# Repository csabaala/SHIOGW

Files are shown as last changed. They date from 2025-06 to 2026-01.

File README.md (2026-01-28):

# [SHIOGW](/Hardware/SHIOGW)

DIN rail mount extension board for [Olimex ESP32-GATEWAY](https://www.olimex.com/Products/IoT/ESP32/ESP32-GATEWAY/open-source-hardware).

More [Pictures](/Pictures#assembled-boards) and [Video](https://youtu.be/ds2y22MUNzQ) of the assembled board and extensions.

Example [ESPHome configs](/ESPHome)

## Features

* 12V to 5V step-down converter
* 2 open collector output (50 mA load per channel)
* 2 opto isolated input
* LEDs for output and input status
* 2 sensor input (ds18b20, dht)
* RS-485 interface
* 4 pin JST connector for I2C extensions
* 14 pin IDC connector for direct GPIO access

View [3D model](https://3dviewer.net/#model=https://github.com/csabaala/SHIOGW/blob/main/Hardware/SHIOGW/SHIOGW.wrl)

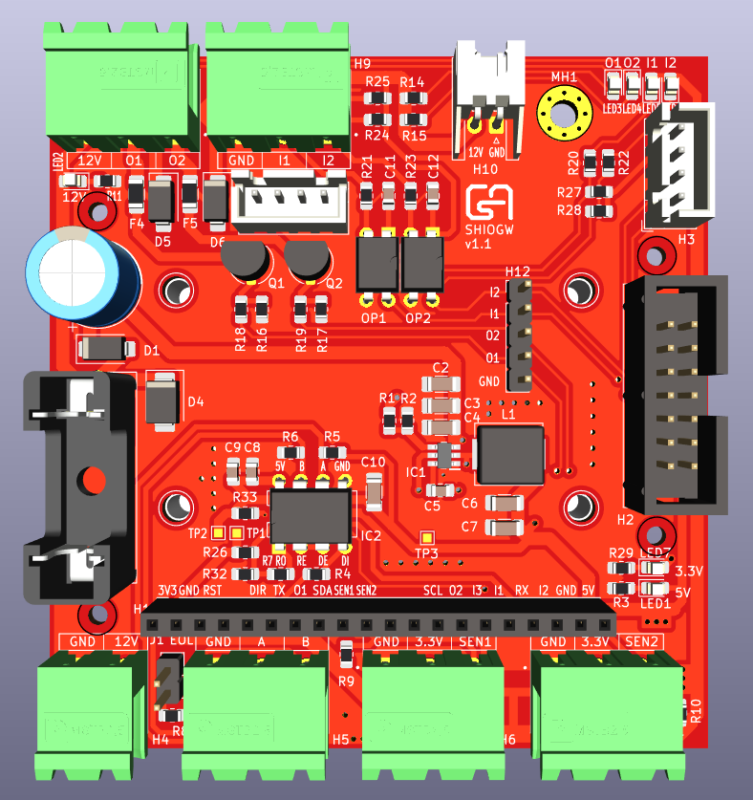
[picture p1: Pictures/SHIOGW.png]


## Extensions

### [GWHMI](/Hardware/GWHMI)

Control interface for SHIOGW.

* PCB for 128x64 OLED display and control buttons. Fits the 0.96 and 1.3 inch OLED versions.
* Mountable top of the SHIOGW board.
* Connects to SHIOGW's 12 pin IDC connector with a small ribbon cable.
* BTN1 (up) and BTN3 (down) shared with I1 and I2 on SHIOGW main board.

View [3D model](https://3dviewer.net/#model=https://github.com/csabaala/SHIOGW/blob/main/Hardware/GWHMI/GWHMI.wrl)

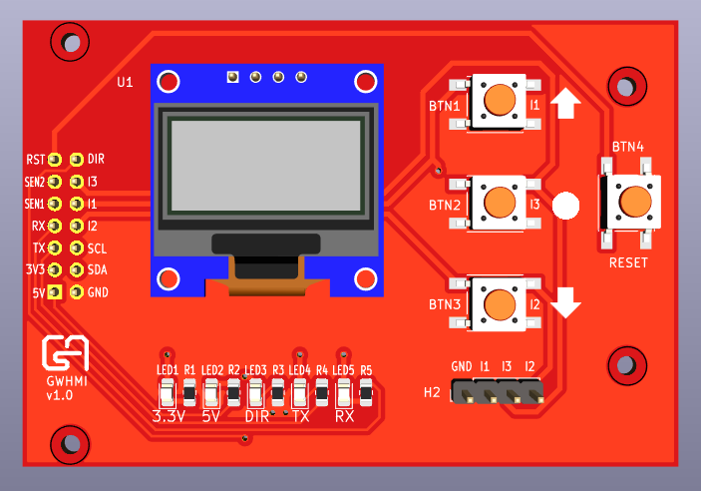
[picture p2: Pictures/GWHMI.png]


### [SHIO88E](/Hardware/SHIO88E)

I2C IO extension.

* MCP23017 based
* 8 open collector output (50 mA load per channel)
* 8 opto isolated input
* LEDs for output and input status
* One more I2C connector to connect other device

View [3D model](https://3dviewer.net/#https://github.com/csabaala/SHIOGW/blob/main/Hardware/SHIO88E/SHIO88E.wrl)

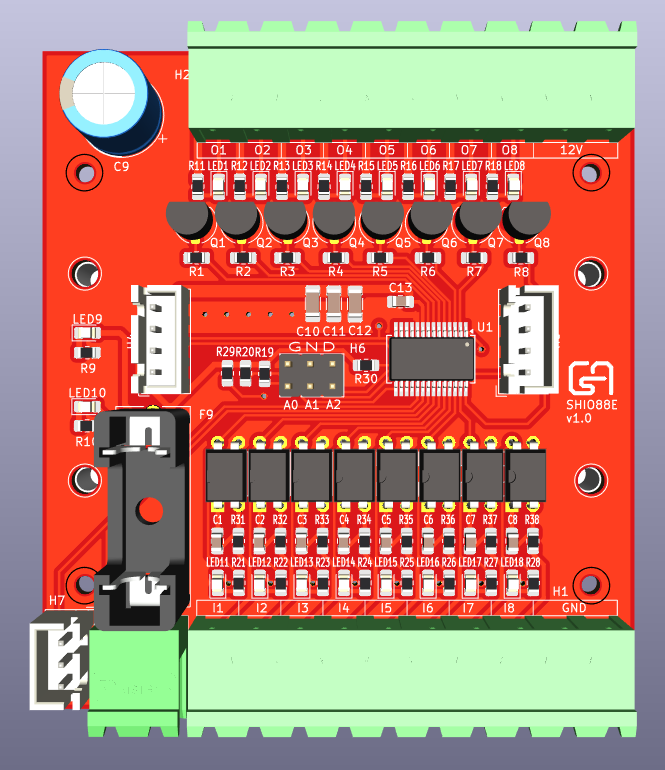
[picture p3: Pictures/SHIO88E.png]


### [LRMNT](/Hardware/LRMNT)

Adapter PCB to mount [Heltec LoRa 32 V3](https://heltec.org/project/wifi-lora-32-v3/) module to SHIOGW board.

* 2 extra open collector output (50 mA load per channel)
* 4 extra opto isolated input

View [3D model](https://3dviewer.net/#https://github.com/csabaala/SHIOGW/blob/main/Hardware/LRMNT/LRMNT.wrl)

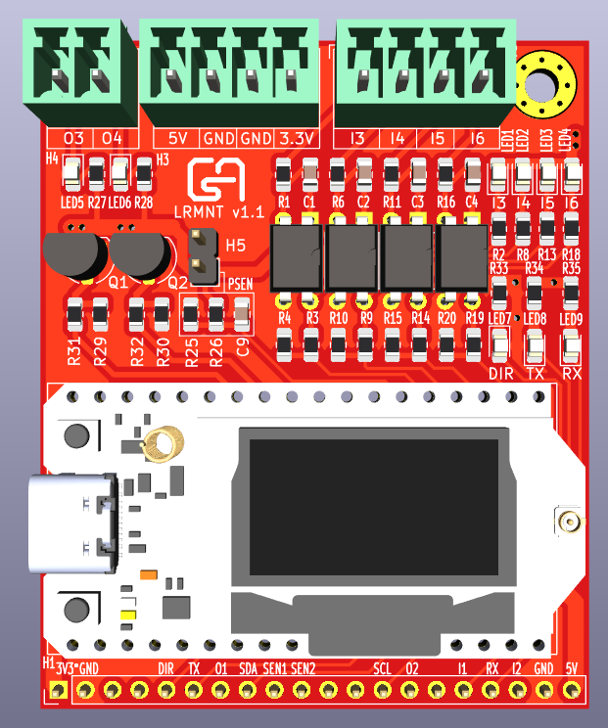
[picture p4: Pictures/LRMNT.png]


### [SHIOADS](/Hardware/SHIOADS)

Din rail mount breakout board for ADS1115 module.

* On board voltage divider resistors (R1 - R8)
* Solder jumpers to set I2C address (JP1 - JP4)

View [3D model](https://3dviewer.net/#https://github.com/csabaala/SHIOGW/blob/main/Hardware/SHIOADS/SHIOADS.wrl)

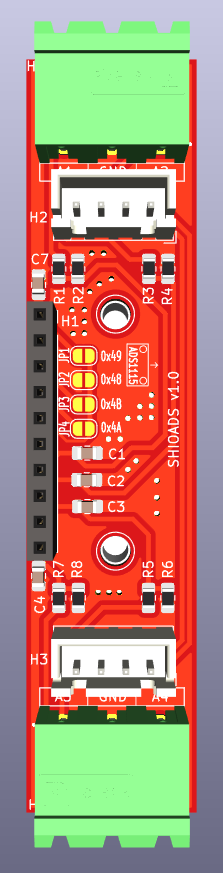
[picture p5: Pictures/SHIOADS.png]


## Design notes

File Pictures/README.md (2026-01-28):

## Assembled boards

The SMD components sitting on the front side of the SHIOGW and SHIOE boards manufactured by JLCPCB SMT assembly.

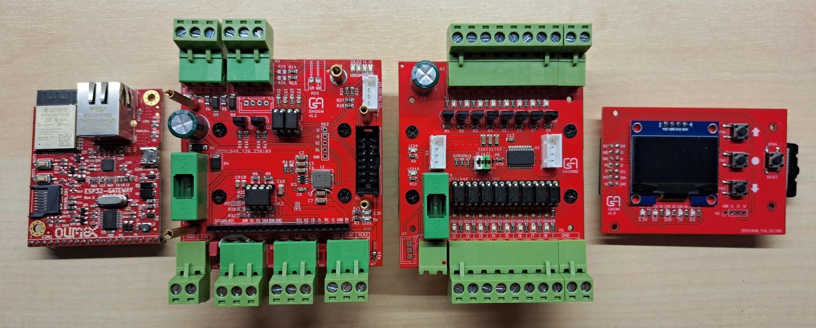
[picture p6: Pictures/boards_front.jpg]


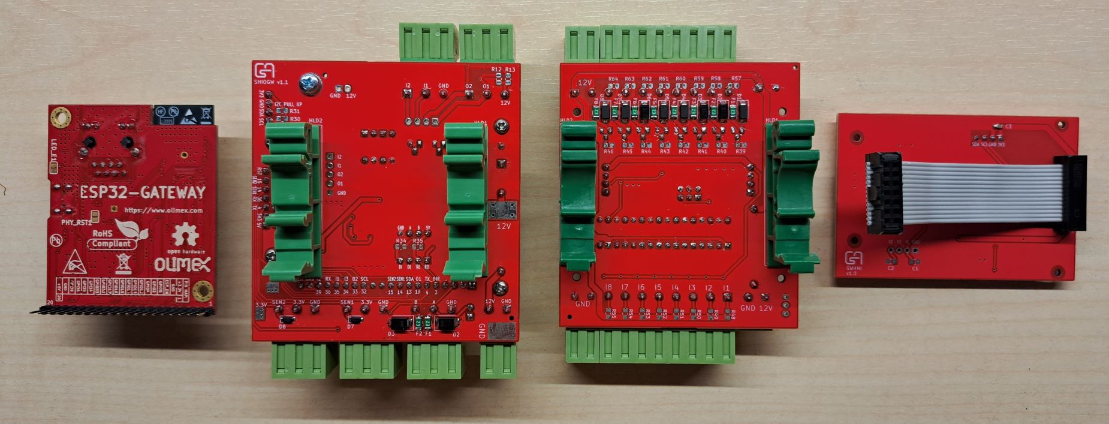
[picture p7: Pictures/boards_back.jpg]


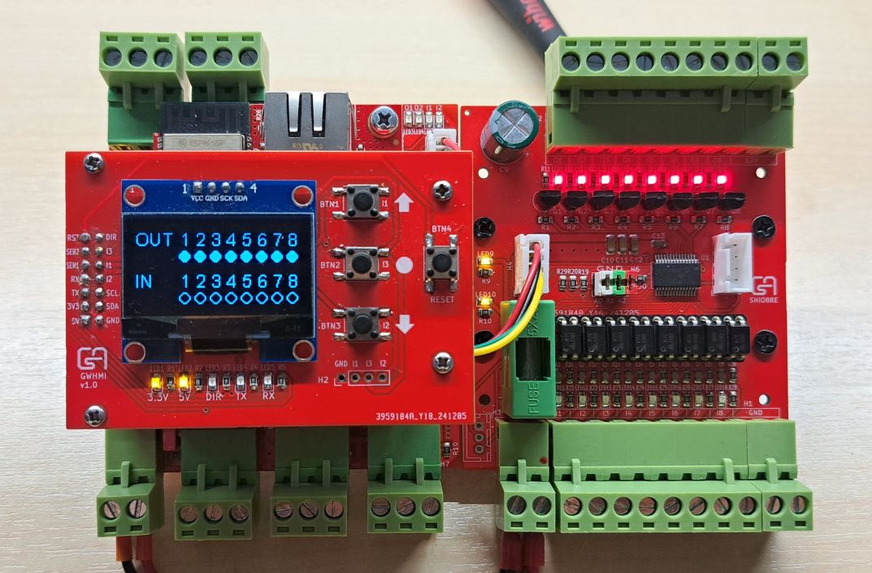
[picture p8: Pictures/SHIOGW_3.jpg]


Fits into home distribution boxes:

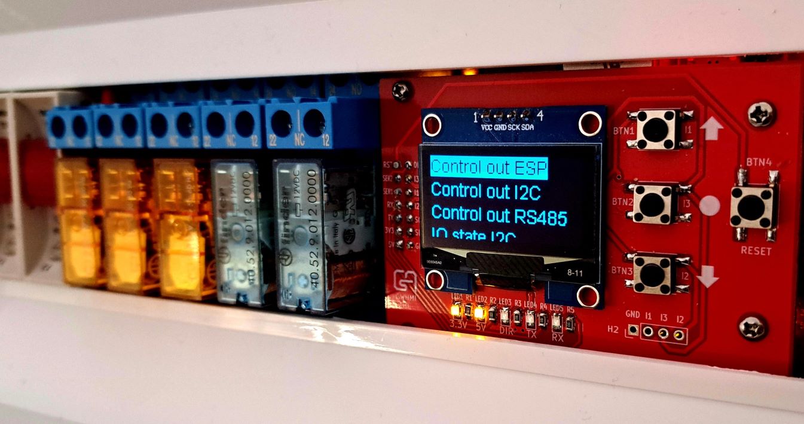
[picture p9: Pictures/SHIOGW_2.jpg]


## SHIOGW and Olimex Gateway

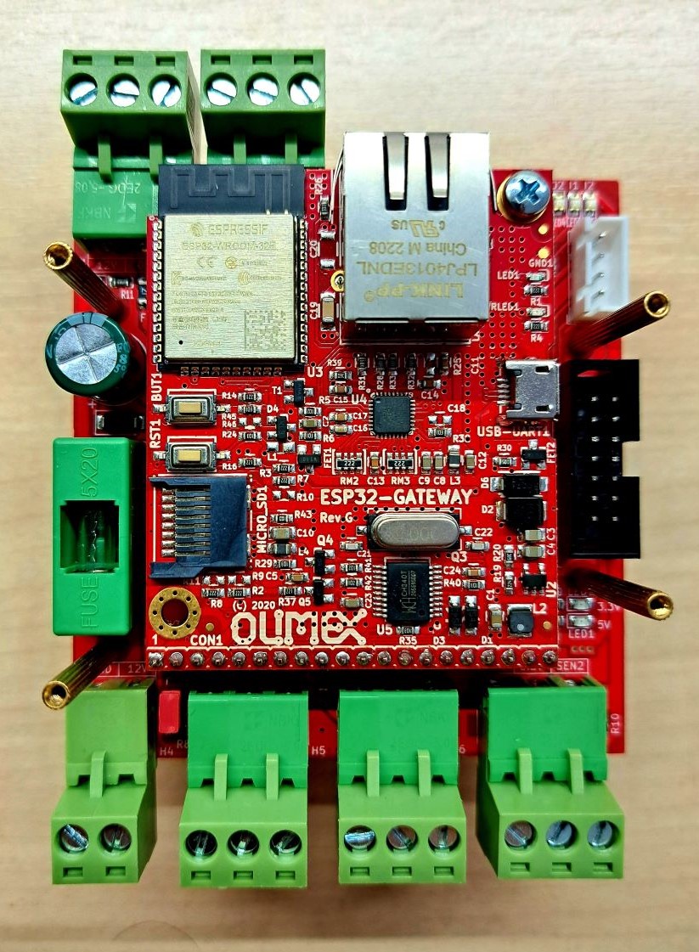
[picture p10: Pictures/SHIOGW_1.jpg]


## SHIO88E

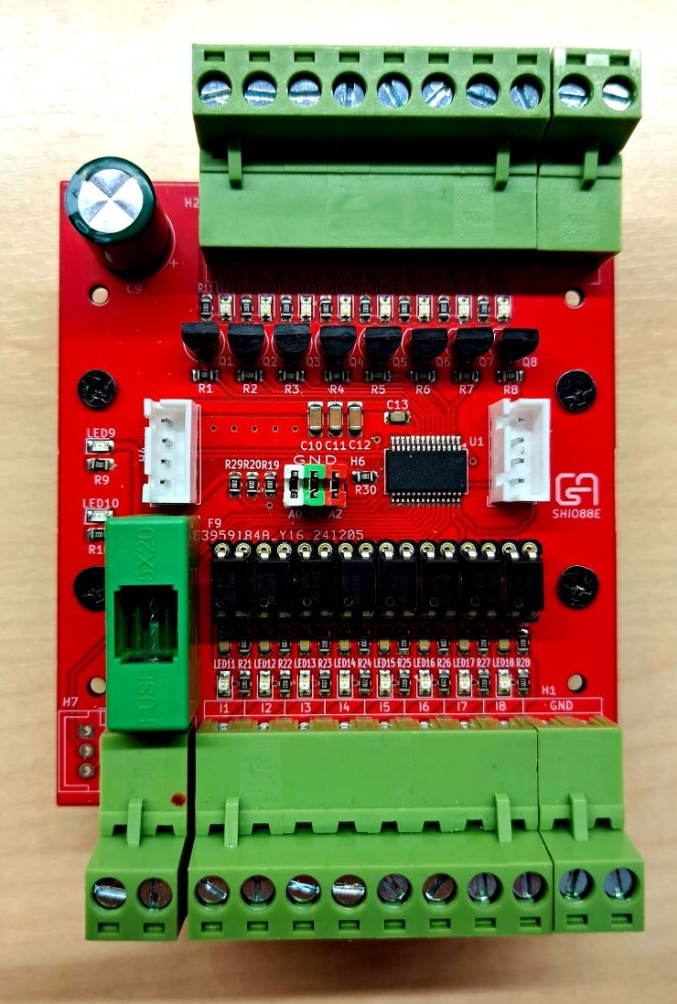
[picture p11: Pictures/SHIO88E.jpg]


## 3D images

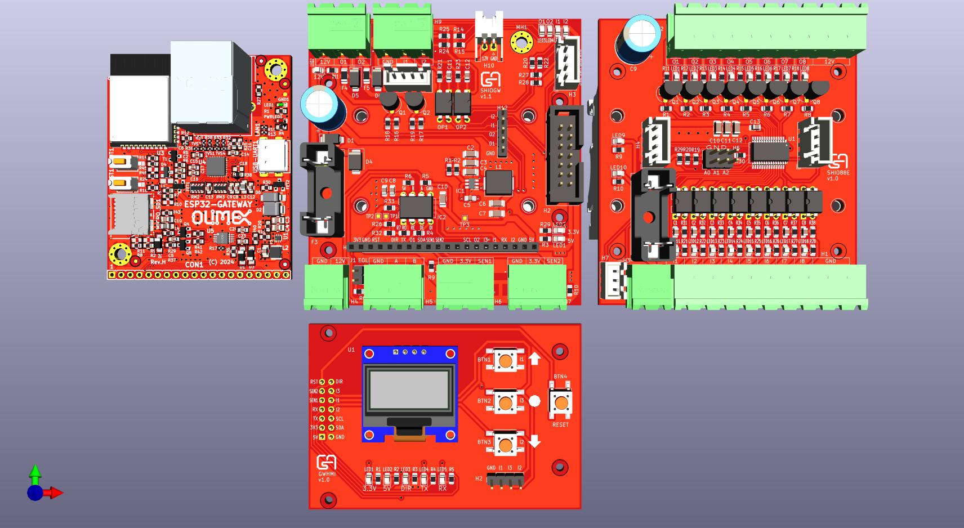
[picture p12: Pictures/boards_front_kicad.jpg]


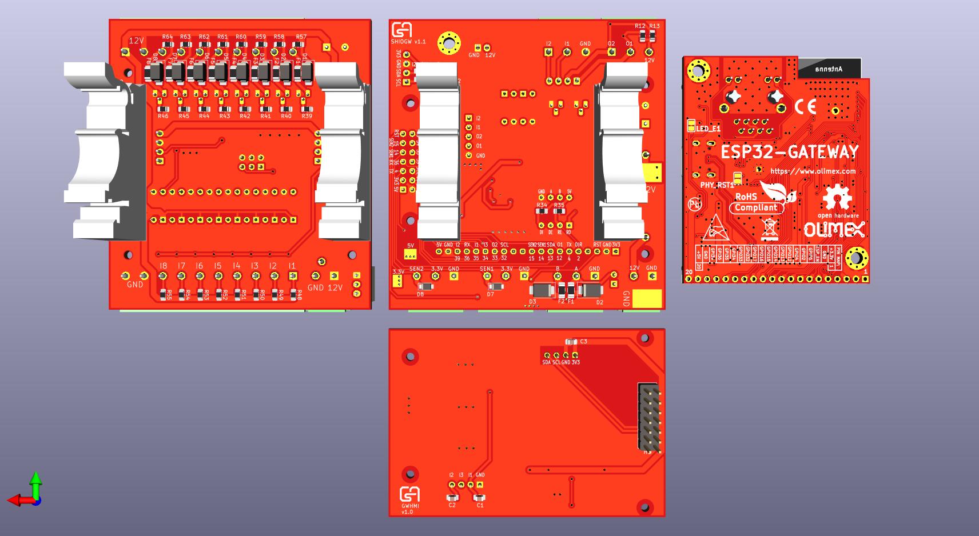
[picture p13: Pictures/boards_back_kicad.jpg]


## LRMNT & SHIOADS

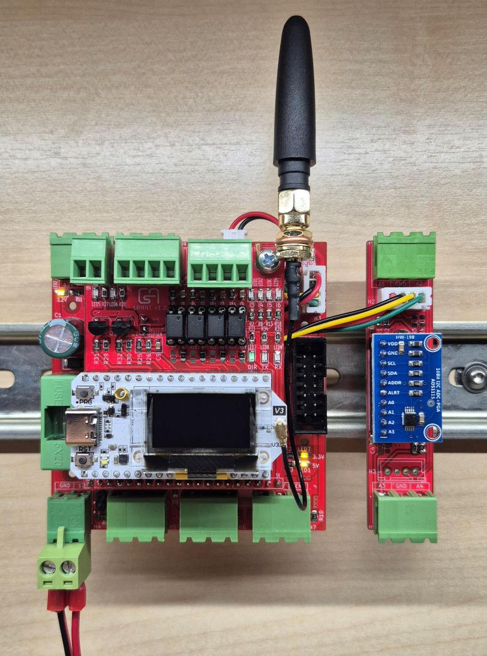
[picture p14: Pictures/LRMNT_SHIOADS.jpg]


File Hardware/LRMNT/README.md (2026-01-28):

# Assembly information
## 12V power source
To activate the additional digital input and output channels, connect the power source to the H5 header.
You can connect to the SHIOGW H10 connector using a JST cable.

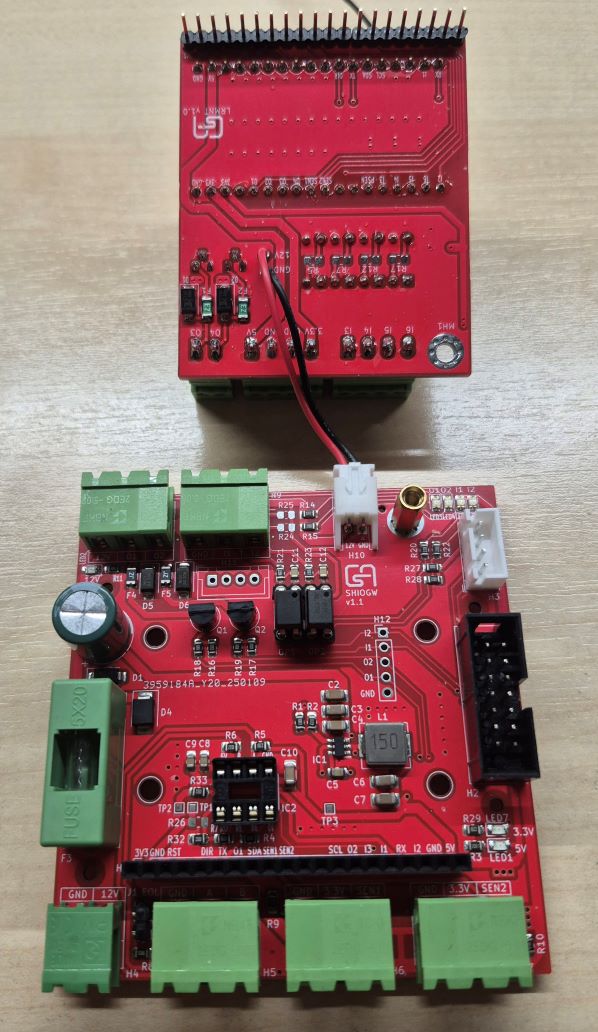
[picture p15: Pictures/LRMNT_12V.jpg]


## Using input channel as ADC
You can soldering the input channels (I3 - I5) to use as ADC (Analog to Digital Converter) input.
To enable ADC reading solder the following parts (for example for I3 channel):

* R1: 0 ohm
* R5: 0 ohm (to bypass OP1)
* R3: Voltage divider high resistor 
* R4: Voltage divider low resistor 
* C5: 100 nF capacitor

Do not solder:

* OP1
* C1

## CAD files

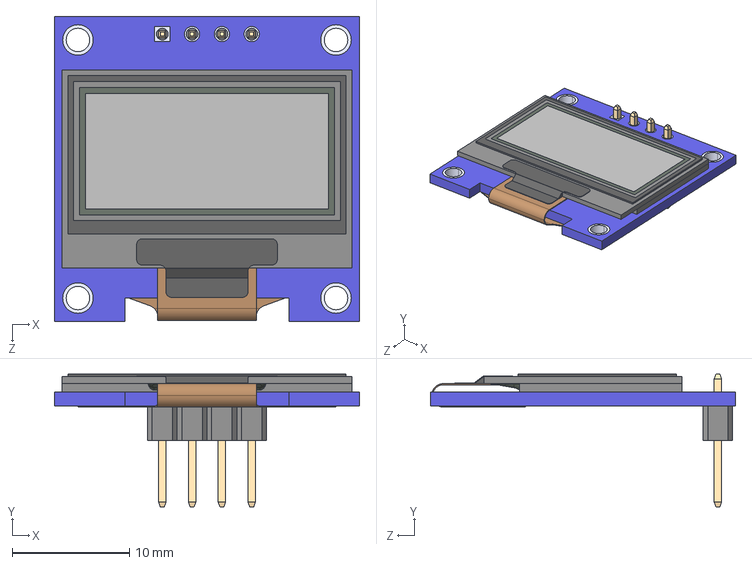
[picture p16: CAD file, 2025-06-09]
Hardware/GWHMI/extras/DM-OLED096-636.step
26.0 x 11.3 x 26.0 mm
DM-OLED096-636_Module
DM-OLED096-636_Panel

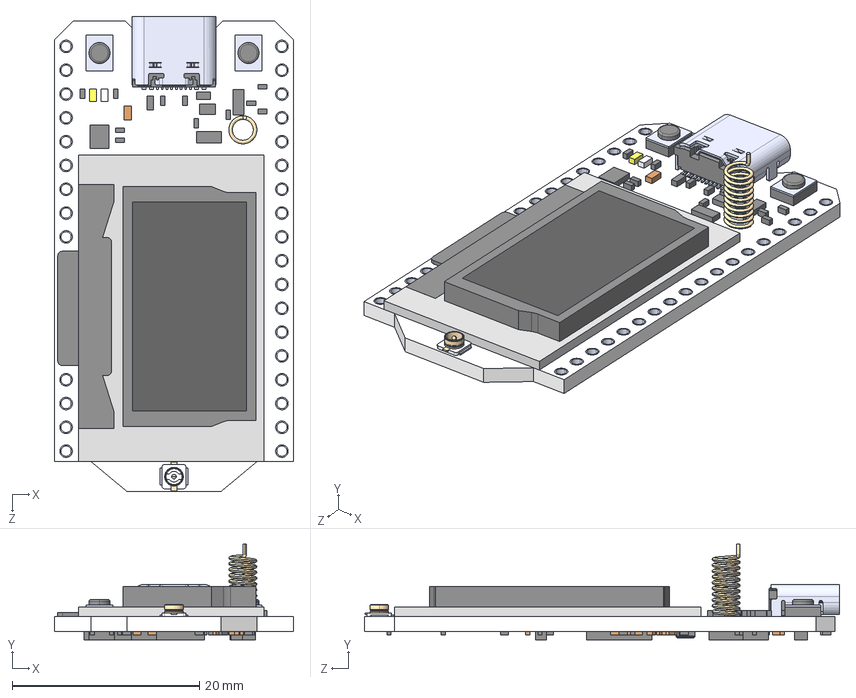
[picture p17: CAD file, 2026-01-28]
Hardware/LRMNT/extras/WIFI_KIT_32__V3_.step
25.5 x 10.2 x 50.7 mm

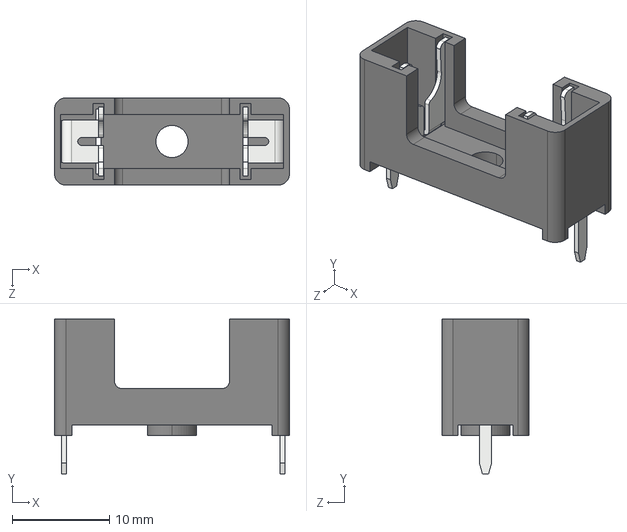
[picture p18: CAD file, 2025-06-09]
Hardware/SHIO88E/extras/fuse/fuse_3d.STEP
24.2 x 16.0 x 8.99 mm

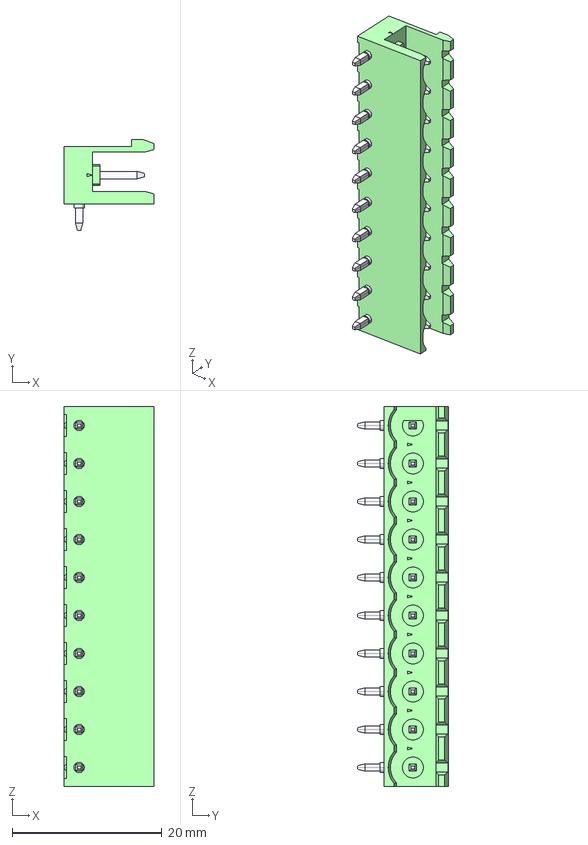
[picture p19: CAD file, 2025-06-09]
Hardware/SHIO88E/extras/MSTB 2,5-10-G-5,08.stp
12.0 x 12.1 x 50.8 mm

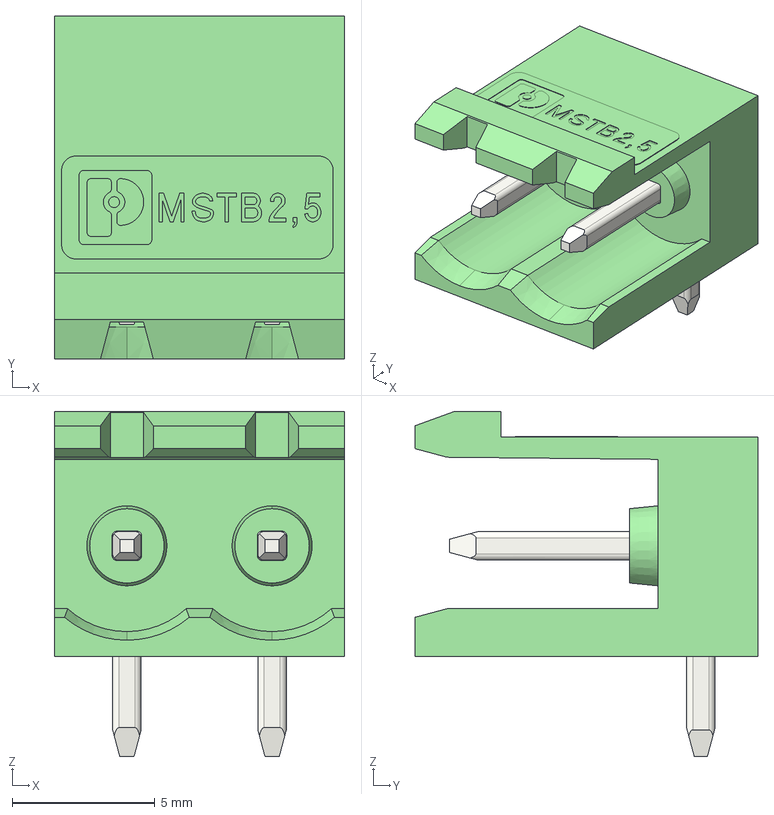
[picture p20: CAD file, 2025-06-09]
Hardware/LRMNT/extras/MSTB 2,5-2-G-5,08.step
10.2 x 12.0 x 12.1 mm

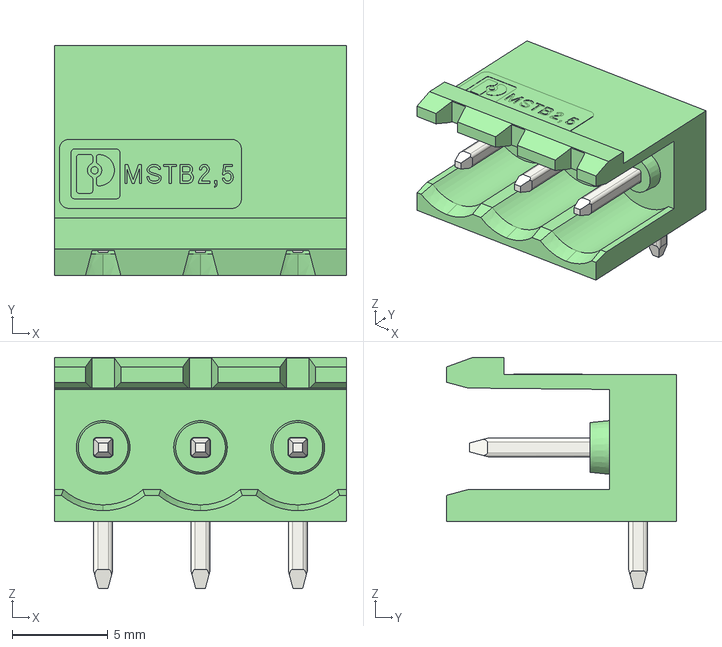
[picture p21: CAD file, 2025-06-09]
Hardware/LRMNT/extras/MSTB 2,5 3-G-5,08/1759020.step
15.2 x 12.0 x 12.1 mm

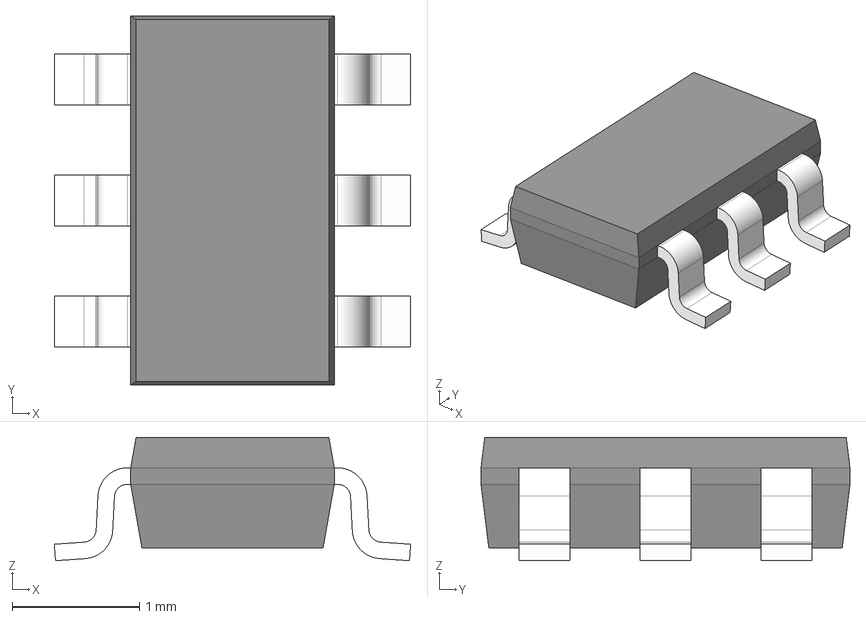
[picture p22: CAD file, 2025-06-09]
Hardware/SHIOGW/extras/LMR51420/LMR51420XDDCR.stp
2.80 x 2.90 x 0.97 mm
BODY-SOT
LEAD-SOT x 6

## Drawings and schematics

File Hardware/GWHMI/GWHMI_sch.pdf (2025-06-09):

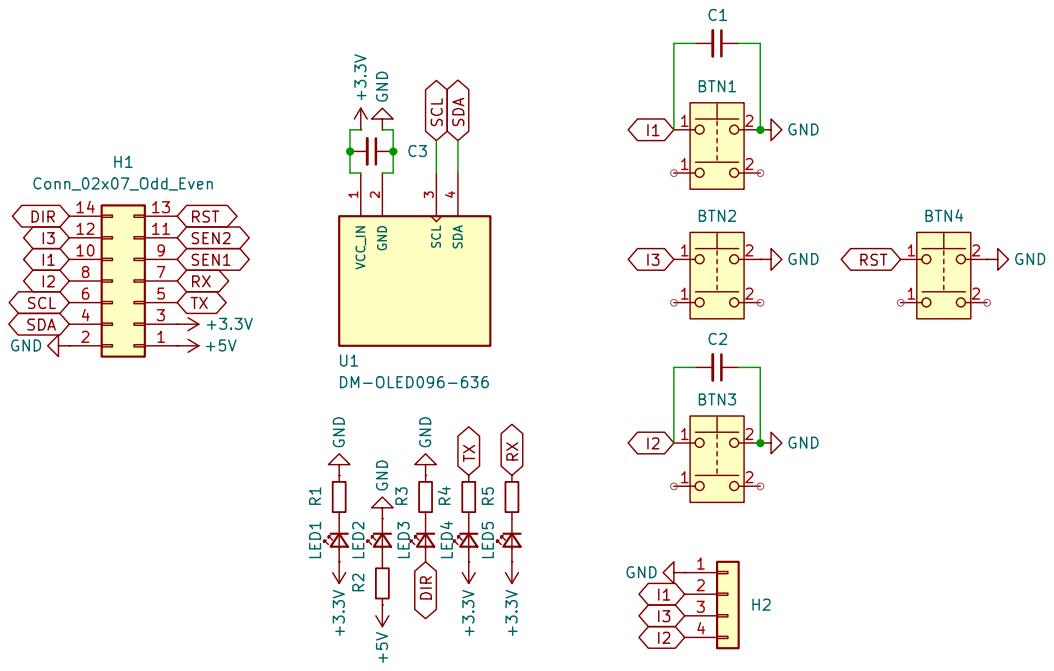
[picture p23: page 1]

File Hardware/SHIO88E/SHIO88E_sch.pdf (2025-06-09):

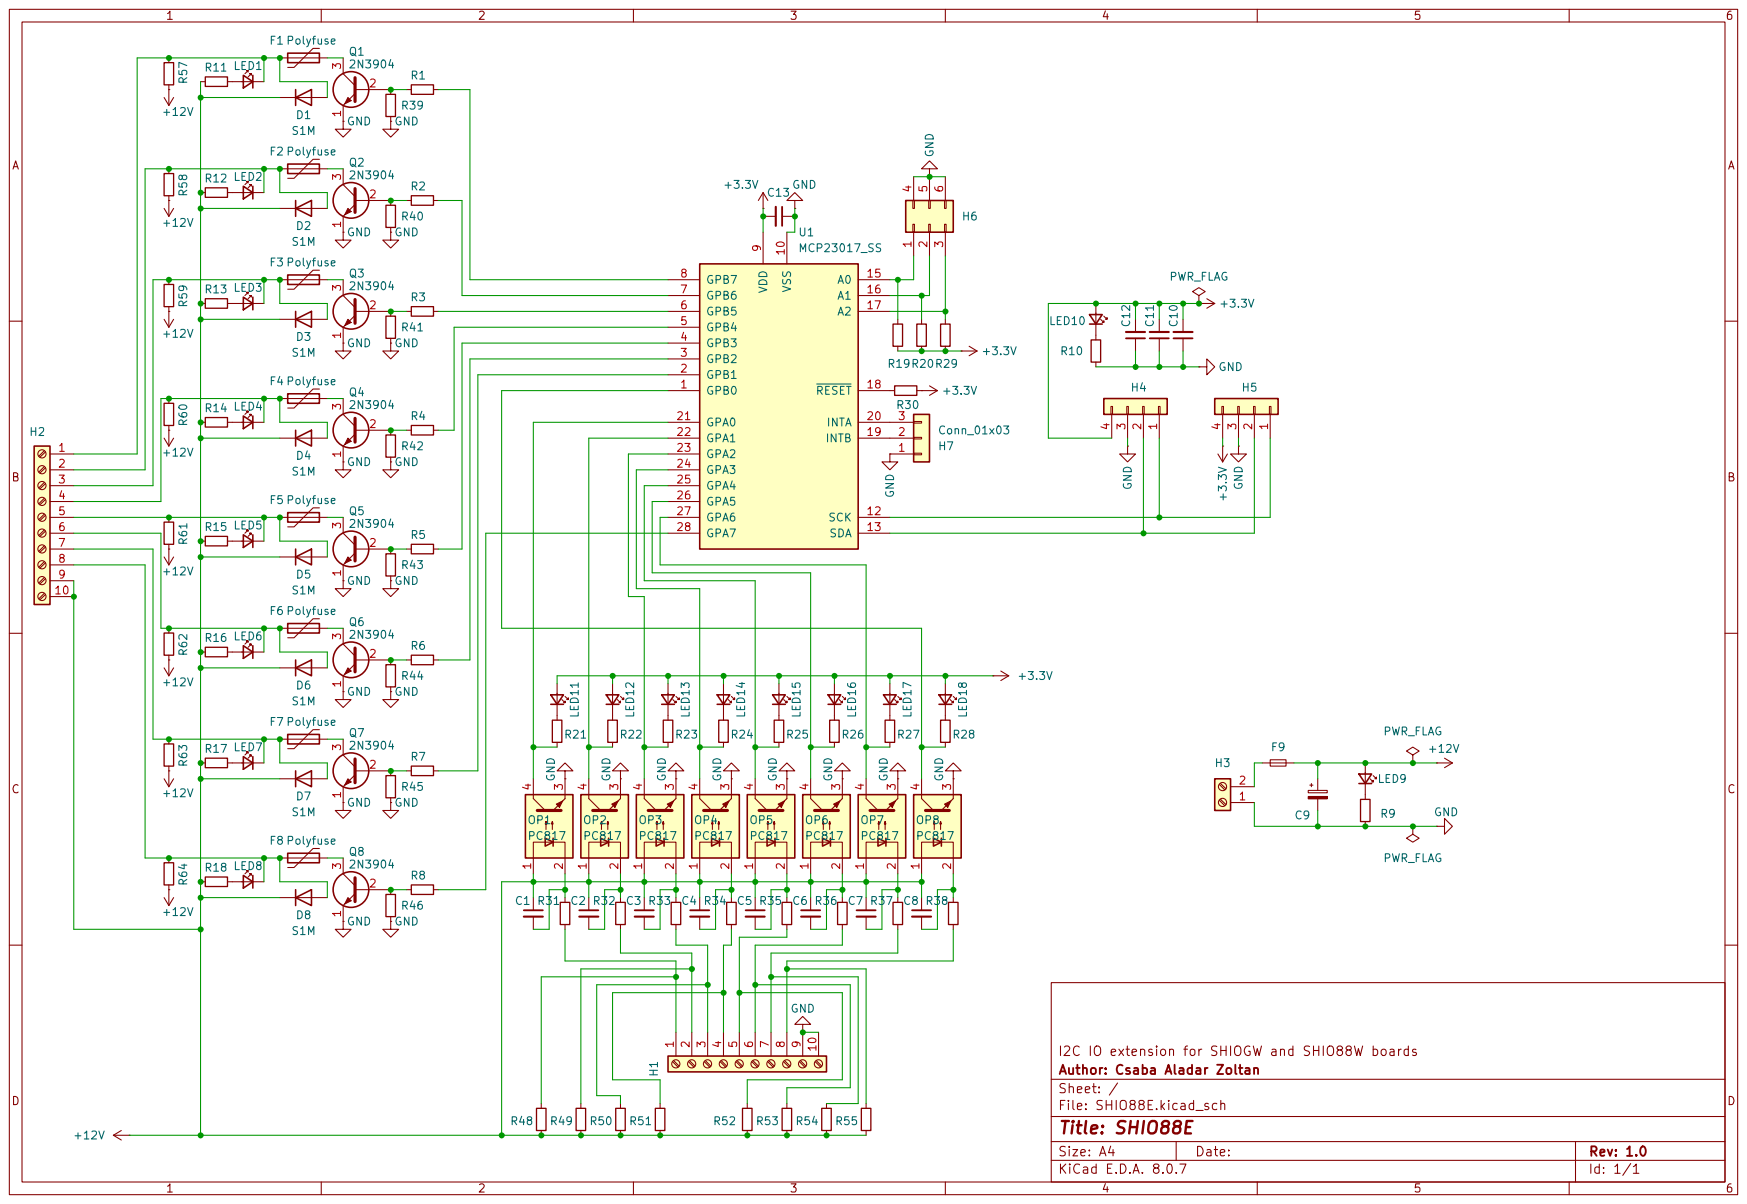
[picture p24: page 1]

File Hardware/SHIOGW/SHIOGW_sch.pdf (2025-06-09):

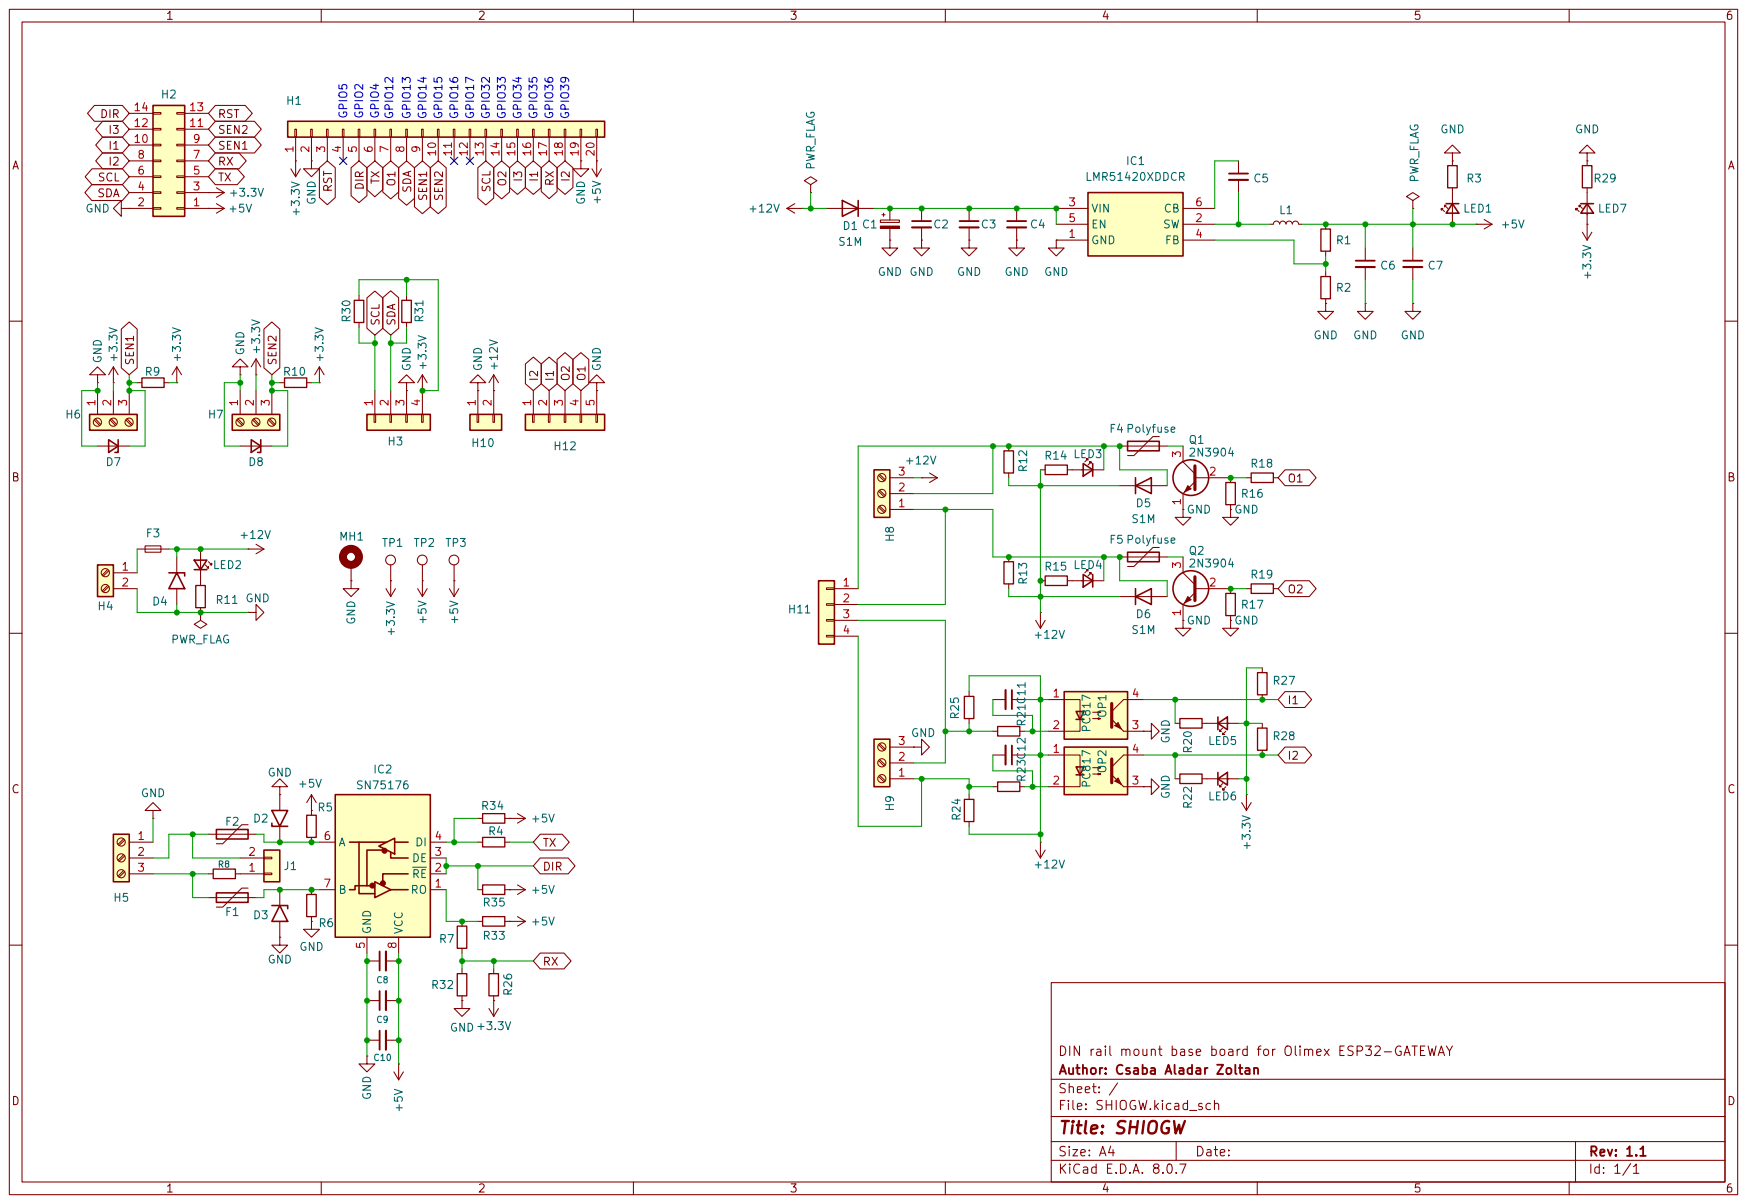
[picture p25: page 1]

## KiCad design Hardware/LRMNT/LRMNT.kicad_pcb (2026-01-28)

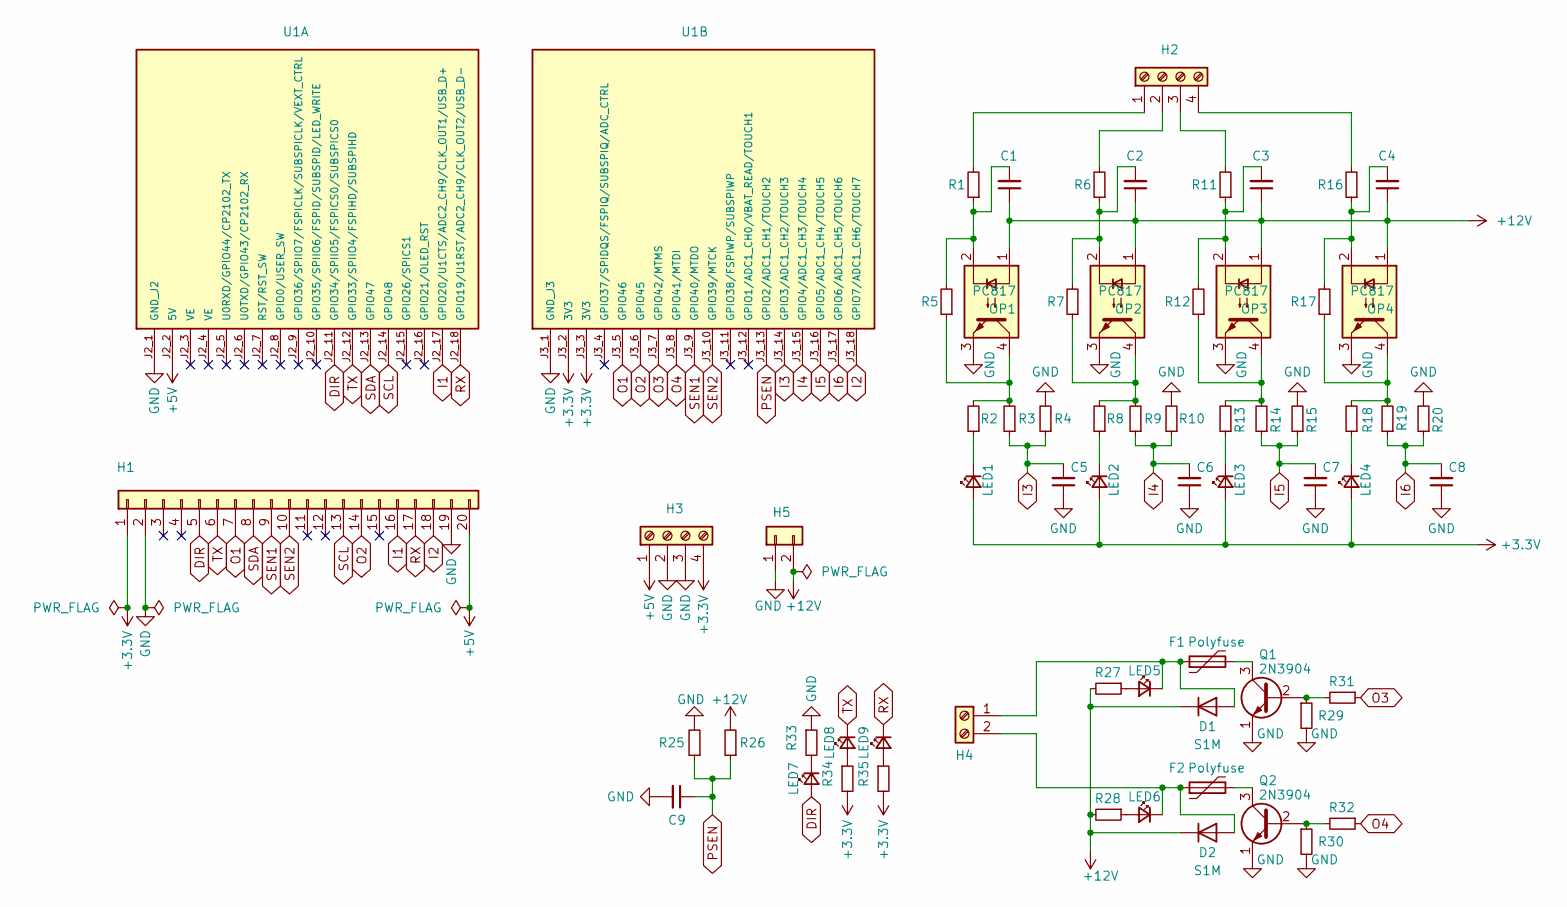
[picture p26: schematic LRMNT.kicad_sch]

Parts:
C1, C2, C3, C4: C_Small; C_0805_2012Metric_Pad1.18x1.45mm_HandSolder; LCSC C1710
C5, C6, C7, C8, C9: C_Small; C_0805_2012Metric_Pad1.18x1.45mm_HandSolder; LCSC C49678
D1, D2: S1M; D_SMA; LCSC C412437
F1, F2: Polyfuse; Fuse_1206_3216Metric_Pad1.42x1.75mm_HandSolder; LCSC C2830235
H1: Conn_01x20; PinHeader_1x20_P2.54mm_Vertical
H2, H3: Screw_Terminal_01x04; PhoenixContact_MCV_1,5_4-G-3.5_1x04_P3.50mm_Vertical
H4: Screw_Terminal_01x02; PhoenixContact_MCV_1,5_2-G-3.5_1x02_P3.50mm_Vertical
H5: Conn_01x02; PinHeader_1x02_P2.54mm_Vertical
LED1, LED2, LED3, LED4, LED5, LED6: LED_Small; LED_0805_2012Metric_Pad1.15x1.40mm_HandSolder; LCSC C84256
LED7, LED8: LED_Small; LED_0805_2012Metric_Pad1.15x1.40mm_HandSolder; LCSC C2297
LED9: LED_Small; LED_0805_2012Metric_Pad1.15x1.40mm_HandSolder; LCSC C2296
OP1, OP2, OP3, OP4: PC817; PC817_custom
Q1, Q2: 2N3904; TO-92_HandSolder
R1, R2, R6, R8, R11, R13, R16, R18, R19, R25, R26: R_Small; R_0805_2012Metric_Pad1.20x1.40mm_HandSolder; LCSC C17520
R3, R4, R5, R7, R9, R10, R12, R14, R15, R17, R20: R_Small; R_0805_2012Metric_Pad1.20x1.40mm_HandSolder
R27, R28, R29, R30, R33, R34, R35: R_Small; R_0805_2012Metric_Pad1.20x1.40mm_HandSolder; LCSC C17414
R31, R32: R_Small; R_0805_2012Metric_Pad1.20x1.40mm_HandSolder; LCSC C17513
U1: WIFI_KIT_32__V3_; MODULE_WIFI_KIT_32__V3_; PARTREV Rev 1.1

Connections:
+3.3V: H1.1, H3.4, LED1.2 (A), LED2.2 (A), LED3.2 (A), LED4.2 (A), R34.2, R35.2, U1.J3_2 (3V3), U1.J3_3 (3V3)
+5V: H1.20, H3.1, U1.J2_2 (5V)
+12V: C1.1, C2.1, C3.1, C4.1, D1.1 (K), D2.1 (K), H5.2, OP1.1, OP2.1, OP3.1, OP4.1, R26.2, R27.2, R28.2
DIR: H1.5, LED7.2 (A), U1.J2_11 (GPIO34/SPIIO5/FSPICS0/SUBSPICS0)
GND: C5.1, C6.1, C7.1, C8.1, C9.2, H1.2, H1.19, H3.2, H3.3, H5.1, OP1.3, OP2.3, OP3.3, OP4.3, Q1.1 (E), Q2.1 (E), R4.2, R10.2, R15.2, R20.2, R25.2, R29.2, R30.2, R33.1, U1.J2_1 (GND_J2), U1.J3_1 (GND_J3); also elsewhere on the board
I1: H1.16, U1.J2_17 (GPIO20/U1CTS/ADC2_CH9/CLK_OUT1/USB_D+)
I2: H1.18, U1.J3_18 (GPIO7/ADC1_CH6/TOUCH7)
I3: C5.2, R3.1, R4.1, U1.J3_14 (GPIO3/ADC1_CH2/TOUCH3)
I4: C6.2, R9.1, R10.1, U1.J3_15 (GPIO4/ADC1_CH3/TOUCH4)
I5: C7.2, R14.1, R15.1, U1.J3_16 (GPIO5/ADC1_CH4/TOUCH5)
I6: C8.2, R19.1, R20.1, U1.J3_17 (GPIO6/ADC1_CH5/TOUCH6)
unnamed: C1.2, OP1.2, R1.1, R5.2
unnamed: C2.2, OP2.2, R6.1, R7.2
unnamed: C3.2, OP3.2, R11.1, R12.2
unnamed: C4.2, OP4.2, R16.1, R17.2
unnamed: D1.2 (A), F1.1, H4.1, LED5.1 (K)
unnamed: D2.2 (A), F2.1, H4.2, LED6.1 (K)
unnamed: H2.1, R1.2
unnamed: H2.2, R6.2
unnamed: H2.3, R11.2
unnamed: H2.4, R16.2
unnamed: LED1.1 (K), R2.1
unnamed: LED2.1 (K), R8.1
unnamed: LED3.1 (K), R13.1
unnamed: LED4.1 (K), R18.1
unnamed: LED5.2 (A), R27.1
unnamed: LED6.2 (A), R28.1
unnamed: LED7.1 (K), R33.2
unnamed: LED8.2 (A), R34.1
unnamed: LED9.2 (A), R35.1
unnamed: OP1.4, R2.2, R3.2, R5.1
unnamed: OP2.4, R7.1, R8.2, R9.2
unnamed: OP3.4, R12.1, R13.2, R14.2
unnamed: OP4.4, R17.1, R18.2, R19.2
unnamed: Q1.2 (B), R29.1, R31.2
unnamed: F1.2, Q1.3 (C)
unnamed: Q2.2 (B), R30.1, R32.2
unnamed: F2.2, Q2.3 (C)
O1: H1.7, U1.J3_5 (GPIO46)
O2: H1.14, U1.J3_6 (GPIO45)
O3: R31.1, U1.J3_7 (GPIO42/MTMS)
O4: R32.1, U1.J3_8 (GPIO41/MTDI)
PSEN: C9.1, R25.1, R26.1, U1.J3_13 (GPIO2/ADC1_CH1/TOUCH2)
RX: H1.17, LED9.1 (K), U1.J2_18 (GPIO19/U1RST/ADC2_CH9/CLK_OUT2/USB_D-)
SCL: H1.13, U1.J2_14 (GPIO48)
SDA: H1.8, U1.J2_13 (GPIO47)
SEN1: H1.9, U1.J3_9 (GPIO40/MTDO)
SEN2: H1.10, U1.J3_10 (GPIO39/MTCK)
TX: H1.6, LED8.1 (K), U1.J2_12 (GPIO33/SPIIO4/FSPIHD/SUBSPIHD)

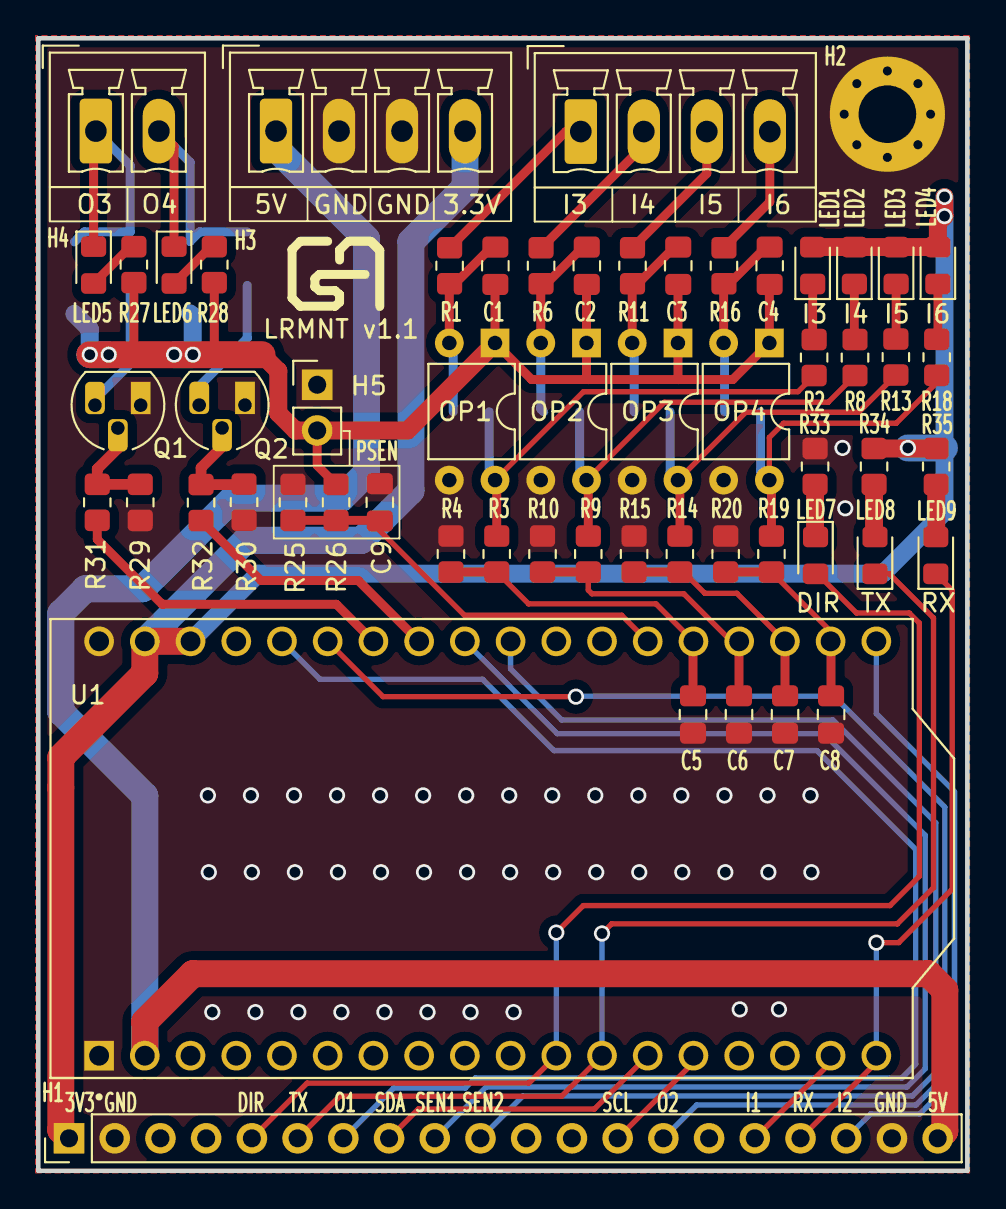
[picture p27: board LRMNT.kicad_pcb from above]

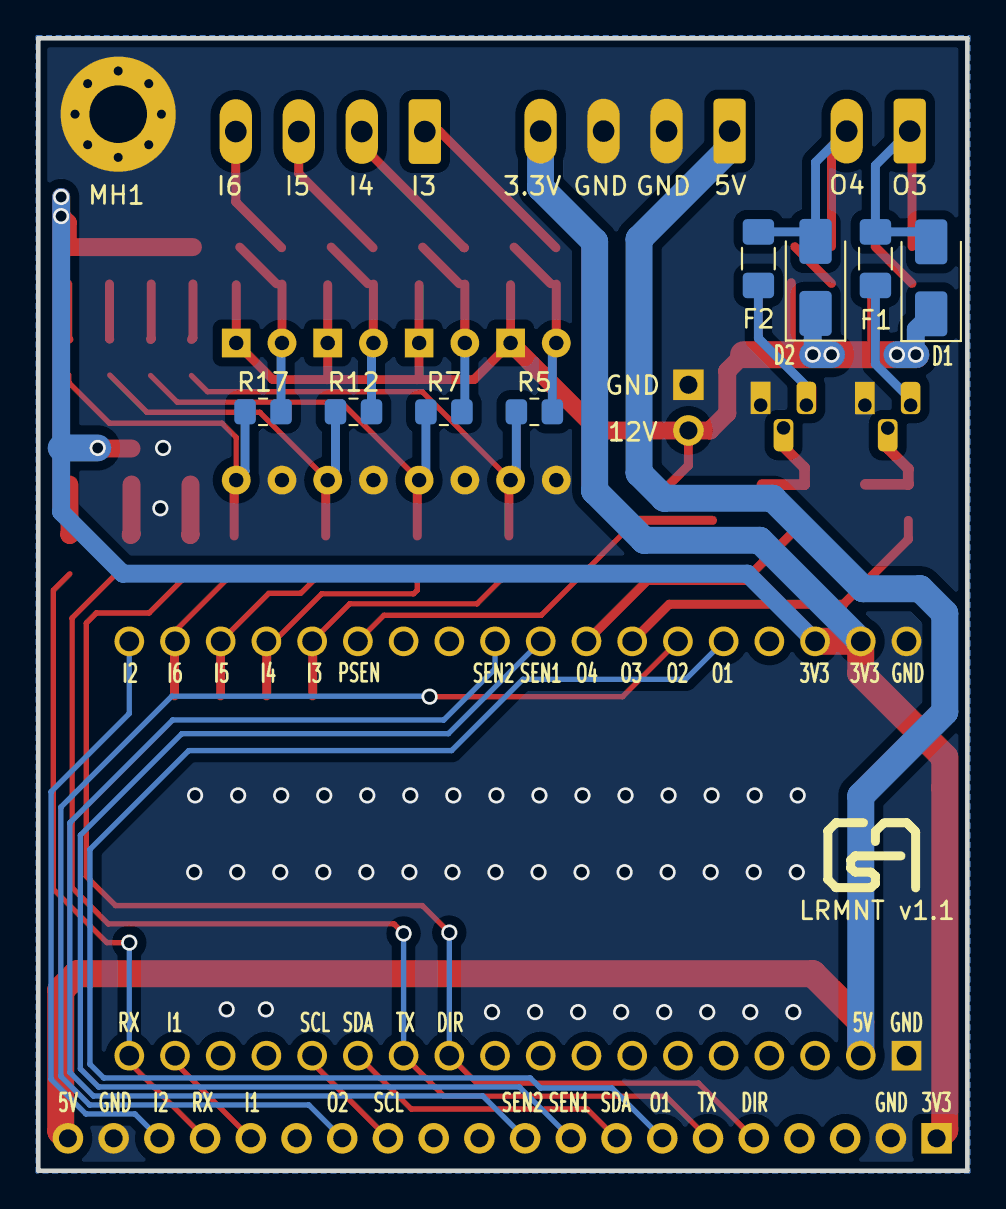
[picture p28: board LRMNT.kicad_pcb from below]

Board: 2 copper layers, 51.6 x 62.9 mm, 66 parts (8 on the bottom side), 49 nets.

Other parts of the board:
MH1: MountingHole_Pad; MountingHole_3.2mm_M3_Pad_Via

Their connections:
GND: MH1.1; also elsewhere on the board

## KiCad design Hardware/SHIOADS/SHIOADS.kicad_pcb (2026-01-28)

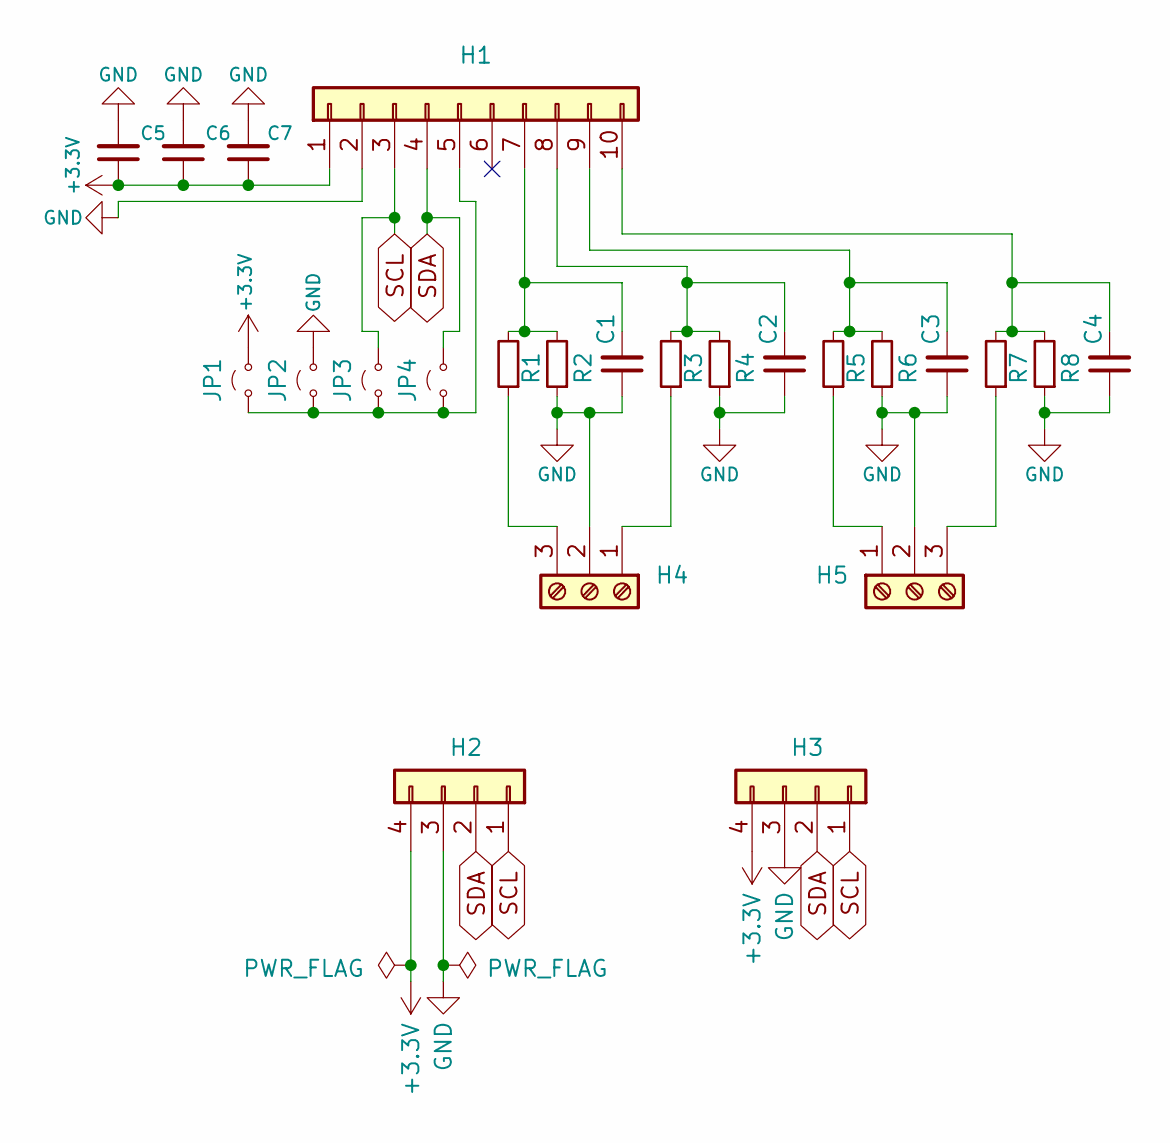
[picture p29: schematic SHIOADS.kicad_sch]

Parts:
C1, C2, C3, C4: C_Small; C_0805_2012Metric_Pad1.18x1.45mm_HandSolder; LCSC C1710
C5, C6: C_Small; C_1206_3216Metric_Pad1.33x1.80mm_HandSolder; LCSC C50254
C7: C_Small; C_0805_2012Metric_Pad1.18x1.45mm_HandSolder; LCSC C49678
H1: Conn_01x10; PinSocket_1x10_P2.54mm_Vertical
H2, H3: Conn_01x04; JST_XH_B4B-XH-A_1x04_P2.50mm_Vertical
H4, H5: Screw_Terminal_01x03; TerminalBlock_MSTB 2,5 3-G-5,08_v3
JP1, JP2, JP3, JP4: Jumper_2_Small_Open; SolderJumper-2_P1.3mm_Open_RoundedPad1.0x1.5mm
R1, R3, R5, R7: R_Small; R_0805_2012Metric_Pad1.20x1.40mm_HandSolder; LCSC C17414
R2, R4, R6, R8: R_Small; R_0805_2012Metric_Pad1.20x1.40mm_HandSolder; LCSC C17513

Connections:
+3.3V: C5.1, C6.1, C7.1, H1.1, H2.4, H3.4, JP1.2 (B)
GND: C1.1, C2.1, C3.1, C4.1, C5.2, C6.2, C7.2, H1.2, H2.3, H3.3, H4.2, H5.2, JP2.2 (B), R2.1, R4.1, R6.1, R8.1
unnamed: H1.5, JP1.1 (A), JP2.1 (A), JP3.1 (A), JP4.1 (A)
unnamed: C1.2, H1.7, R1.2, R2.2
unnamed: C2.2, H1.8, R3.2, R4.2
unnamed: C3.2, H1.9, R5.2, R6.2
unnamed: C4.2, H1.10, R7.2, R8.2
unnamed: H4.1, R3.1
unnamed: H4.3, R1.1
unnamed: H5.1, R5.1
unnamed: H5.3, R7.1
SCL: H1.3, H2.1, H3.1, JP3.2 (B)
SDA: H1.4, H2.2, H3.2, JP4.2 (B)

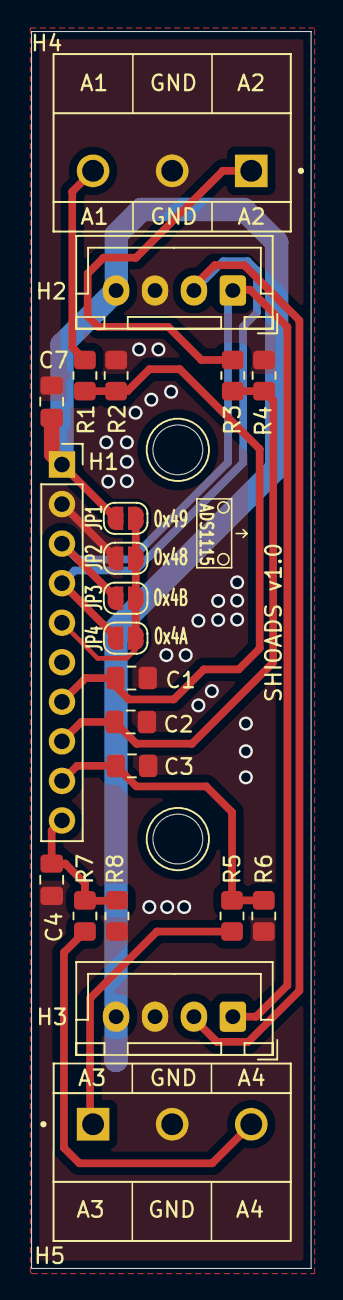
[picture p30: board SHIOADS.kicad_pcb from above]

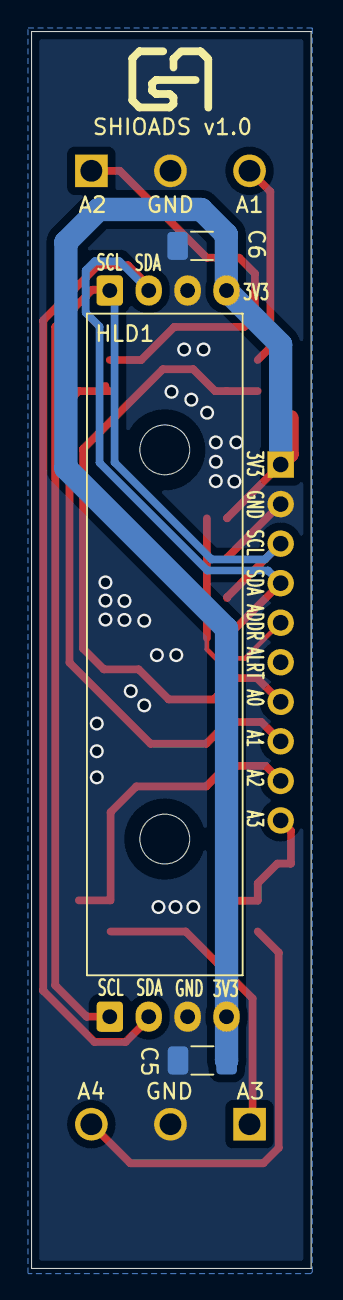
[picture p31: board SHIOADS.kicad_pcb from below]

Board: 2 copper layers, 18.0 x 79.5 mm, 25 parts (2 on the bottom side), 13 nets.

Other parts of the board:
HLD1: DINRailAdapter_3xM3_PhoenixContact_1201578

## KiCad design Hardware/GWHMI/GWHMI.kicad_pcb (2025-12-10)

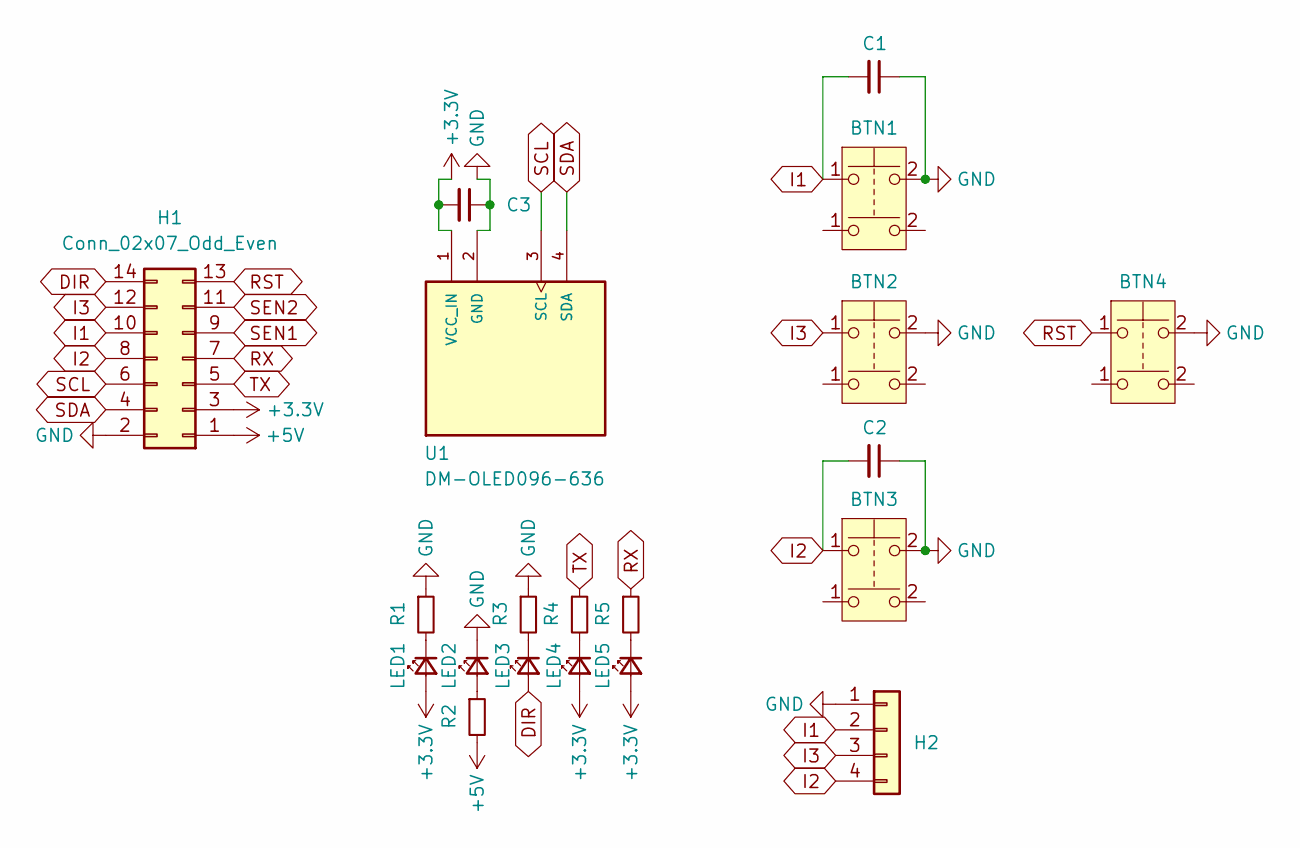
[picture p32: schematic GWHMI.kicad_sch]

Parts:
BTN1, BTN2, BTN3, BTN4: SW_Push_Dual; SW_SPST_PTS645_handsolder
C1, C2, C3: C_Small; C_0805_2012Metric_Pad1.18x1.45mm_HandSolder; LCSC C49678
H1: Conn_02x07_Odd_Even; PinHeader_2x07_P2.54mm_Vertical
H2: Conn_01x04; PinHeader_1x04_P2.54mm_Vertical
LED1, LED5: LED_Small; LED_0805_2012Metric_Pad1.15x1.40mm_HandSolder; LCSC C2296
LED2: LED_Small; LED_0805_2012Metric_Pad1.15x1.40mm_HandSolder; LCSC C84256
LED3, LED4: LED_Small; LED_0805_2012Metric_Pad1.15x1.40mm_HandSolder; LCSC C2297
R1: R_Small; R_0805_2012Metric_Pad1.20x1.40mm_HandSolder; LCSC C17520
R2: R_Small; R_0805_2012Metric_Pad1.20x1.40mm_HandSolder; LCSC C17661
R3, R4, R5: R_Small; R_0805_2012Metric_Pad1.20x1.40mm_HandSolder; LCSC C17414
U1: DM-OLED096-636; display_oled_128x64_i2c; PARTREV 2018-09-10

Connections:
+3.3V: C3.2, H1.3, LED1.2 (A), LED4.2 (A), LED5.2 (A), U1.1 (VCC_IN)
+5V: H1.1, R2.2
DIR: H1.14, LED3.2 (A)
GND: BTN1.2, BTN2.2, BTN3.2, BTN4.2, C1.1, C2.1, C3.1, H1.2, H2.1, LED2.1 (K), R1.1, R3.1, U1.2 (GND)
I1: BTN1.1, C1.2, H1.10, H2.2
I2: BTN3.1, C2.2, H1.8, H2.4
I3: BTN2.1, H1.12, H2.3
unnamed: LED1.1 (K), R1.2
unnamed: LED2.2 (A), R2.1
unnamed: LED3.1 (K), R3.2
unnamed: LED4.1 (K), R4.2
unnamed: LED5.1 (K), R5.2
RST: BTN4.1, H1.13
RX: H1.7, R5.1
SCL: H1.6, U1.3 (SCL)
SDA: H1.4, U1.4 (SDA)
SEN1: H1.9
SEN2: H1.11
TX: H1.5, R4.1

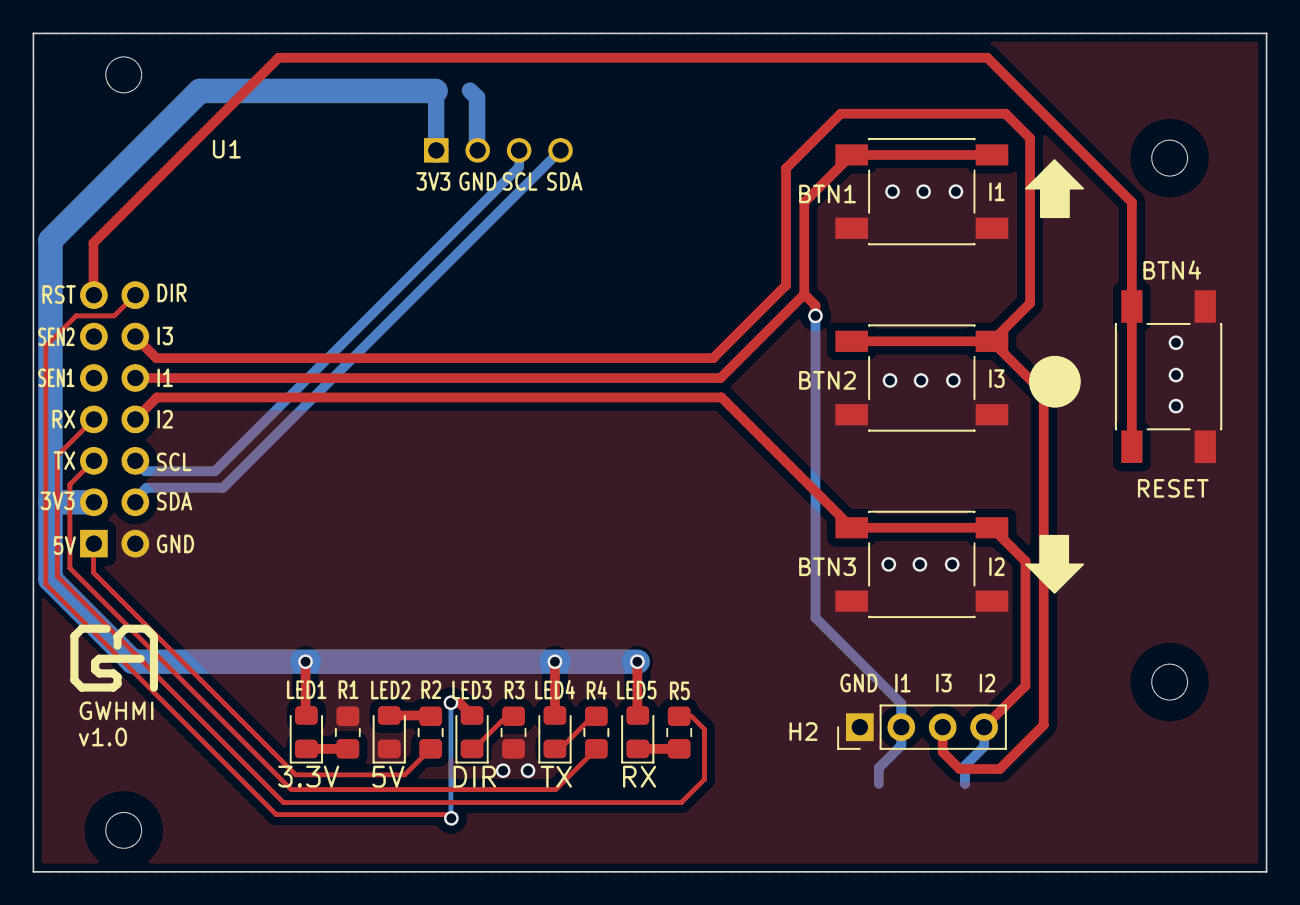
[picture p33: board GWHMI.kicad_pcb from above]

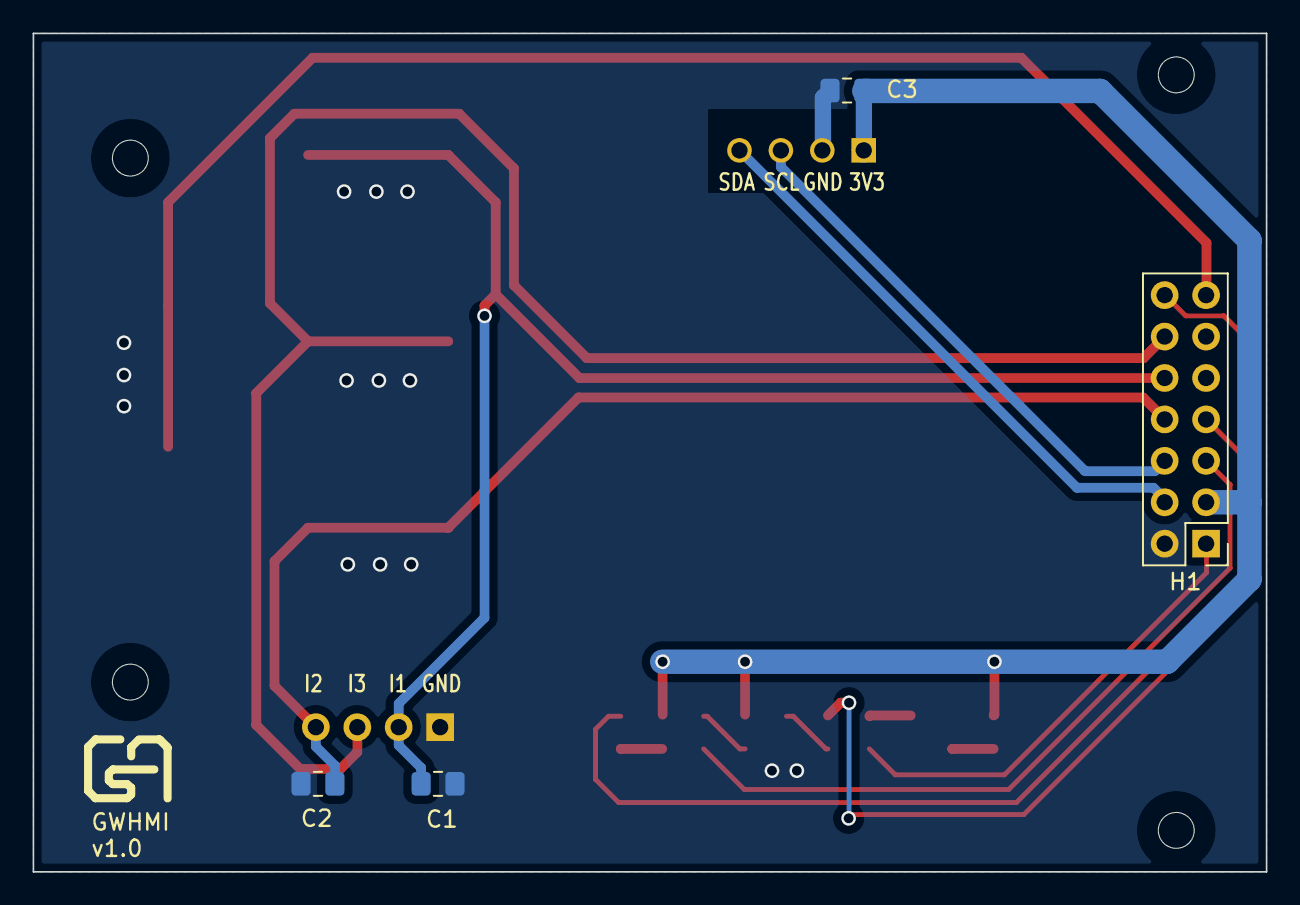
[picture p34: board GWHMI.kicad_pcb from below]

Board: 2 copper layers, 75.6 x 51.4 mm, 20 parts (4 on the bottom side), 17 nets.

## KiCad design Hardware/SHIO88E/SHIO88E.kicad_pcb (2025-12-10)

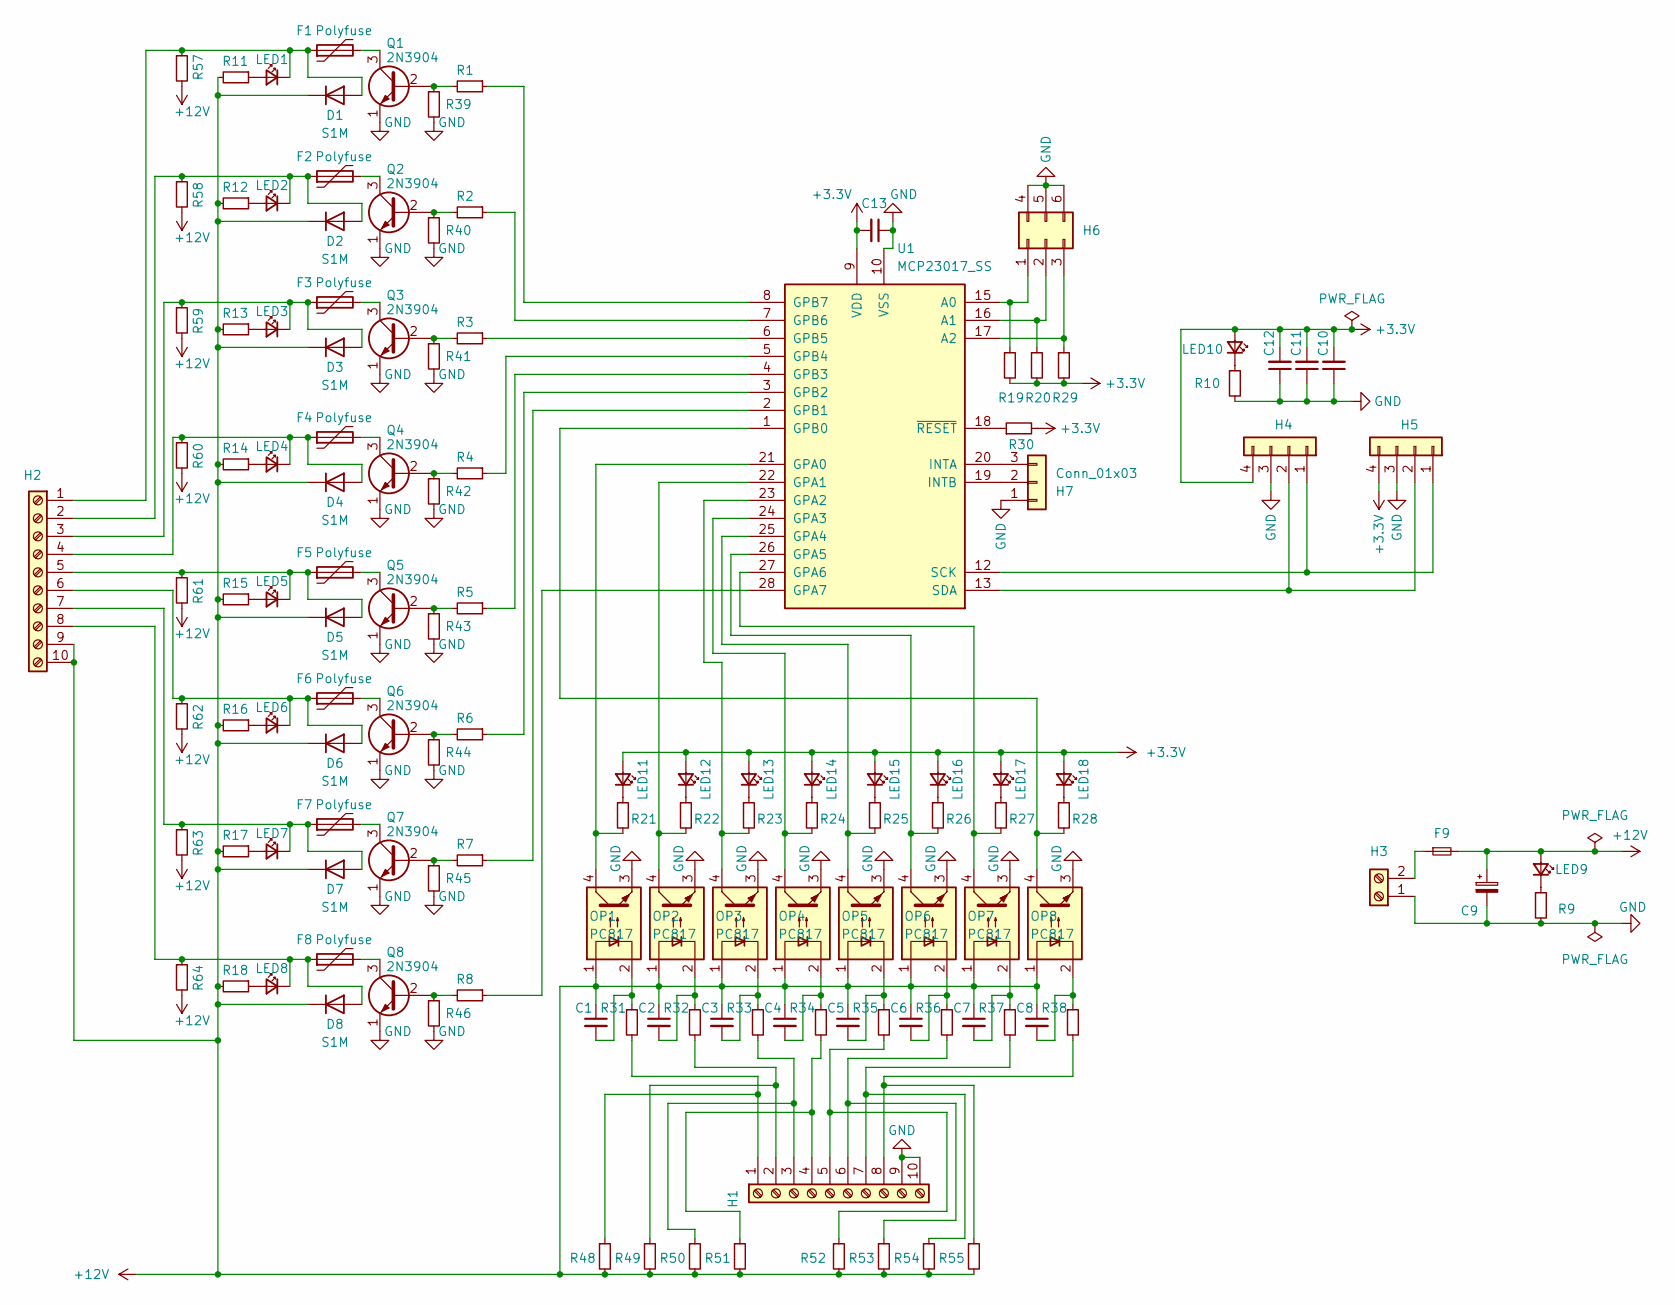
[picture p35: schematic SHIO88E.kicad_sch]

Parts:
C1, C2, C3, C4, C5, C6, C7, C8: C_Small; C_0805_2012Metric_Pad1.18x1.45mm_HandSolder; LCSC C1710
C9: C_Polarized_Small; CP_Radial_D10.0mm_P5.00mm
C10, C11, C12: C_Small; C_1206_3216Metric_Pad1.33x1.80mm_HandSolder; LCSC C13585
C13: C_Small; C_0805_2012Metric_Pad1.18x1.45mm_HandSolder; LCSC C49678
D1, D2, D3, D4, D5, D6, D7, D8: S1M; D_SMA
F1, F2, F3, F4, F5, F6, F7, F8: Polyfuse; Fuse_1206_3216Metric_Pad1.42x1.75mm_HandSolder
F9: Fuse_Small; FUSE_holder
H1, H2: Screw_Terminal_01x10; MSTB 2,5-10-G-5,08_custom
H3: Screw_Terminal_01x02; MSTB 2,5-2-G-5,08
H4, H5: Conn_01x04; JST_XH_B4B-XH-A_1x04_P2.50mm_Vertical
H6: Conn_02x03_Top_Bottom; PinHeader_2x03_P2.54mm_Vertical
H7: Conn_01x03; JST_XH_B3B-XH-A_1x03_P2.50mm_Vertical
LED1, LED2, LED3, LED4, LED5, LED6, LED7, LED8, LED11, LED12, LED13, LED14, LED15, LED16, LED17, LED18: LED_Small; LED_0805_2012Metric_Pad1.15x1.40mm_HandSolder; LCSC C84256
LED9, LED10: LED_Small; LED_0805_2012Metric_Pad1.15x1.40mm_HandSolder; LCSC C2296
OP1, OP2, OP3, OP4, OP5, OP6, OP7, OP8: PC817; PC817_custom
Q1, Q2, Q3, Q4, Q5, Q6, Q7, Q8: 2N3904; TO-92_HandSolder
R1, R2, R3, R4, R5, R6, R7, R8: R_Small; R_0805_2012Metric_Pad1.20x1.40mm_HandSolder; LCSC C17513
R9, R11, R12, R13, R14, R15, R16, R17, R18, R19, R20, R29, R30: R_Small; R_0805_2012Metric_Pad1.20x1.40mm_HandSolder; LCSC C17414
R10, R21, R22, R23, R24, R25, R26, R27, R28, R31, R32, R33, R34, R35, R36, R37, R38: R_Small; R_0805_2012Metric_Pad1.20x1.40mm_HandSolder; LCSC C17520
R39, R40, R41, R42, R43, R44, R45, R46, R48, R49, R50, R51, R52, R53, R54, R55, R57, R58, R59, R60, R61, R62, R63, R64: R_Small; R_0805_2012Metric_Pad1.20x1.40mm_HandSolder
U1: MCP23017_SS; SSOP-28_5.3x10.2mm_P0.65mm; LCSC C558584

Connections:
+3.3V: C10.2, C11.2, C12.2, C13.2, H4.4, H5.4, LED10.2 (A), LED11.2 (A), LED12.2 (A), LED13.2 (A), LED14.2 (A), LED15.2 (A), LED16.2 (A), LED17.2 (A), LED18.2 (A), R19.2, R20.2, R29.2, R30.2, U1.9 (VDD)
+12V: C1.1, C2.1, C3.1, C4.1, C5.1, C6.1, C7.1, C8.1, C9.1, D1.1 (K), D2.1 (K), D3.1 (K), D4.1 (K), D5.1 (K), D6.1 (K), D7.1 (K), D8.1 (K), F9.2, H2.9, H2.10, LED9.2 (A), OP1.1, OP2.1, OP3.1, OP4.1, OP5.1, OP6.1, OP7.1, OP8.1, R11.2, R12.2, R13.2, R14.2, R15.2, R16.2, R17.2, R18.2, R48.2, R49.2, R50.2, R51.2, R52.2, R53.2, R54.2, R55.2, R57.2, R58.2, R59.2, R60.2, R61.2, R62.2, R63.2, R64.2
GND: C9.2, C10.1, C11.1, C12.1, C13.1, H1.9, H1.10, H3.1, H4.3, H5.3, H6.4, H6.5, H6.6, H7.1, OP1.3, OP2.3, OP3.3, OP4.3, OP5.3, OP6.3, OP7.3, OP8.3, Q1.1 (E), Q2.1 (E), Q3.1 (E), Q4.1 (E), Q5.1 (E), Q6.1 (E), Q7.1 (E), Q8.1 (E), R9.2, R10.2, R39.2, R40.2, R41.2, R42.2, R43.2, R44.2, R45.2, R46.2, U1.10 (VSS)
unnamed: C1.2, OP1.2, R31.1
unnamed: C2.2, OP2.2, R32.1
unnamed: C3.2, OP3.2, R33.1
unnamed: C4.2, OP4.2, R34.1
unnamed: C5.2, OP5.2, R35.1
unnamed: C6.2, OP6.2, R36.1
unnamed: C7.2, OP7.2, R37.1
unnamed: C8.2, OP8.2, R38.1
unnamed: D1.2 (A), F1.1, H2.1, LED1.1 (K), R57.1
unnamed: D2.2 (A), F2.1, H2.2, LED2.1 (K), R58.1
unnamed: D3.2 (A), F3.1, H2.3, LED3.1 (K), R59.1
unnamed: D4.2 (A), F4.1, H2.4, LED4.1 (K), R60.1
unnamed: D5.2 (A), F5.1, H2.5, LED5.1 (K), R61.1
unnamed: D6.2 (A), F6.1, H2.6, LED6.1 (K), R62.1
unnamed: D7.2 (A), F7.1, H2.7, LED7.1 (K), R63.1
unnamed: D8.2 (A), F8.1, H2.8, LED8.1 (K), R64.1
unnamed: H1.1, R31.2, R48.1
unnamed: H1.2, R32.2, R49.1
unnamed: H1.3, R33.2, R50.1
unnamed: H1.4, R34.2, R51.1
unnamed: H1.5, R35.2, R52.1
unnamed: H1.6, R36.2, R53.1
unnamed: H1.7, R37.2, R54.1
unnamed: H1.8, R38.2, R55.1
unnamed: F9.1, H3.2
unnamed: H4.1, H5.1, U1.12 (SCK)
unnamed: H4.2, H5.2, U1.13 (SDA)
unnamed: H6.1, R19.1, U1.15 (A0)
unnamed: H6.2, R20.1, U1.16 (A1)
unnamed: H6.3, R29.1, U1.17 (A2)
unnamed: H7.2, U1.19 (INTB)
unnamed: H7.3, U1.20 (INTA)
unnamed: LED1.2 (A), R11.1
unnamed: LED2.2 (A), R12.1
unnamed: LED3.2 (A), R13.1
unnamed: LED4.2 (A), R14.1
unnamed: LED5.2 (A), R15.1
unnamed: LED6.2 (A), R16.1
unnamed: LED7.2 (A), R17.1
unnamed: LED8.2 (A), R18.1
unnamed: LED9.1 (K), R9.1
unnamed: LED10.1 (K), R10.1
unnamed: LED11.1 (K), R21.1
unnamed: LED12.1 (K), R22.1
unnamed: LED13.1 (K), R23.1
unnamed: LED14.1 (K), R24.1
unnamed: LED15.1 (K), R25.1
unnamed: LED16.1 (K), R26.1
unnamed: LED17.1 (K), R27.1
unnamed: LED18.1 (K), R28.1
unnamed: Q1.2 (B), R1.2, R39.1
unnamed: F1.2, Q1.3 (C)
unnamed: Q2.2 (B), R2.2, R40.1
unnamed: F2.2, Q2.3 (C)
unnamed: Q3.2 (B), R3.2, R41.1
unnamed: F3.2, Q3.3 (C)
unnamed: Q4.2 (B), R4.2, R42.1
unnamed: F4.2, Q4.3 (C)
unnamed: Q5.2 (B), R5.2, R43.1
unnamed: F5.2, Q5.3 (C)
unnamed: Q6.2 (B), R6.2, R44.1
unnamed: F6.2, Q6.3 (C)
unnamed: Q7.2 (B), R7.2, R45.1
unnamed: F7.2, Q7.3 (C)
unnamed: Q8.2 (B), R8.2, R46.1
unnamed: F8.2, Q8.3 (C)
unnamed: OP1.4, R21.2, U1.21 (GPA0)
unnamed: OP2.4, R22.2, U1.22 (GPA1)
unnamed: OP3.4, R23.2, U1.23 (GPA2)
unnamed: OP4.4, R24.2, U1.24 (GPA3)
unnamed: OP5.4, R25.2, U1.25 (GPA4)
unnamed: OP6.4, R26.2, U1.26 (GPA5)
unnamed: OP7.4, R27.2, U1.27 (GPA6)
unnamed: R8.1, U1.28 (GPA7)
unnamed: OP8.4, R28.2, U1.1 (GPB0)
unnamed: R7.1, U1.2 (GPB1)
unnamed: R6.1, U1.3 (GPB2)
unnamed: R5.1, U1.4 (GPB3)
unnamed: R4.1, U1.5 (GPB4)
unnamed: R3.1, U1.6 (GPB5)
unnamed: R2.1, U1.7 (GPB6)
unnamed: R1.1, U1.8 (GPB7)
unnamed: R30.1, U1.18 (~RESET)

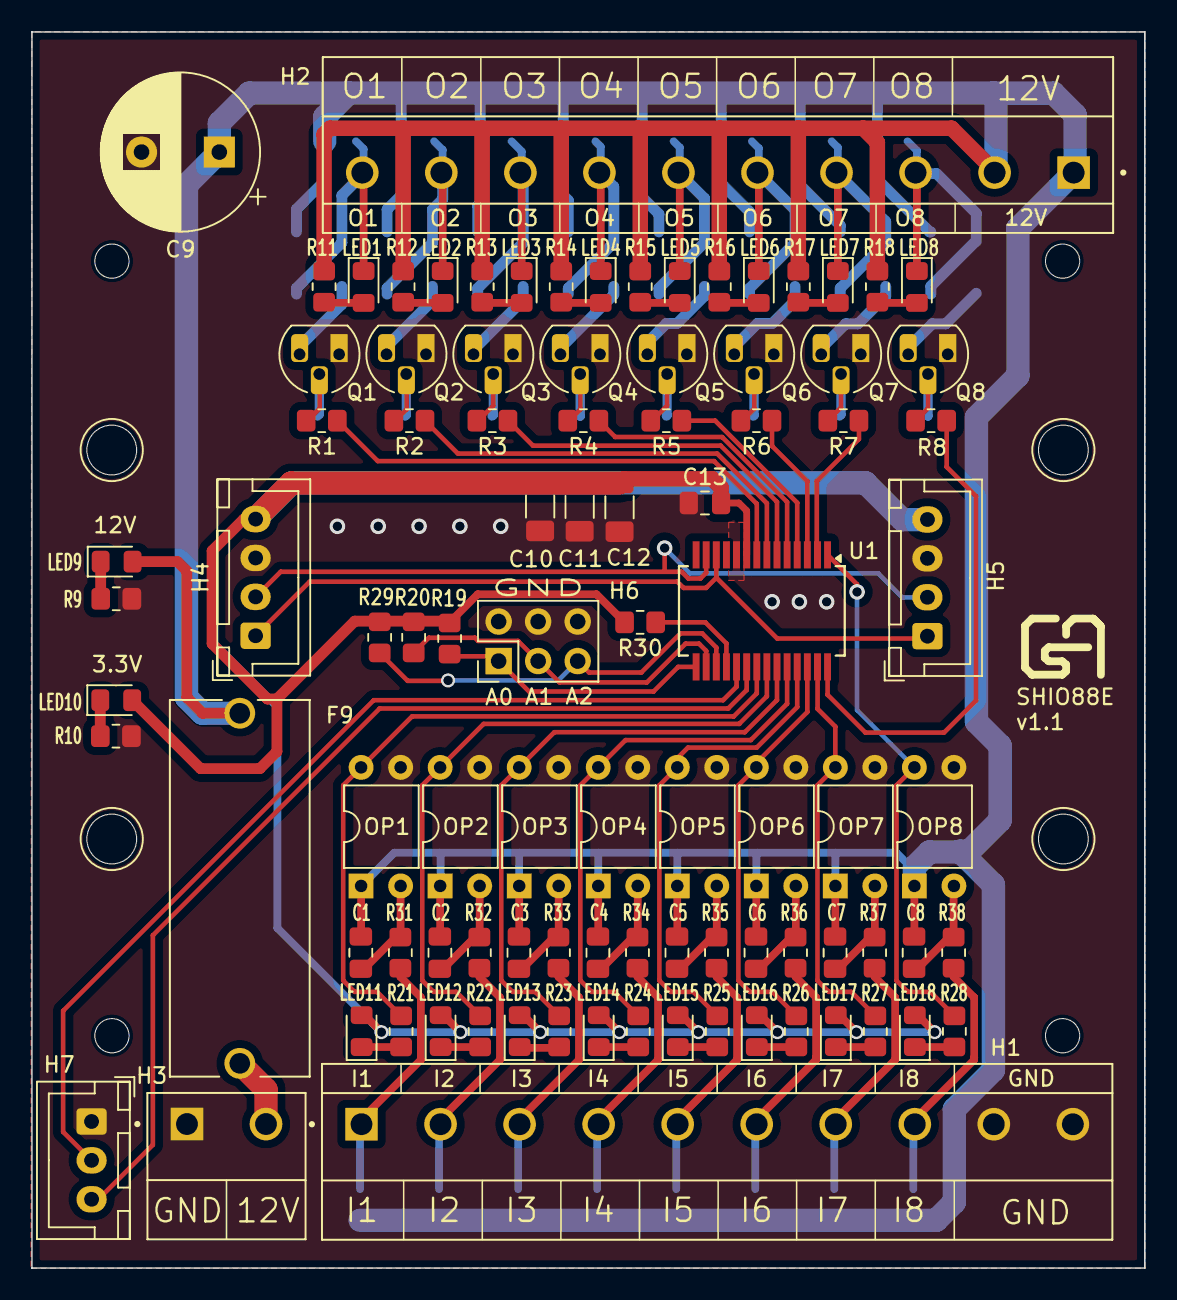
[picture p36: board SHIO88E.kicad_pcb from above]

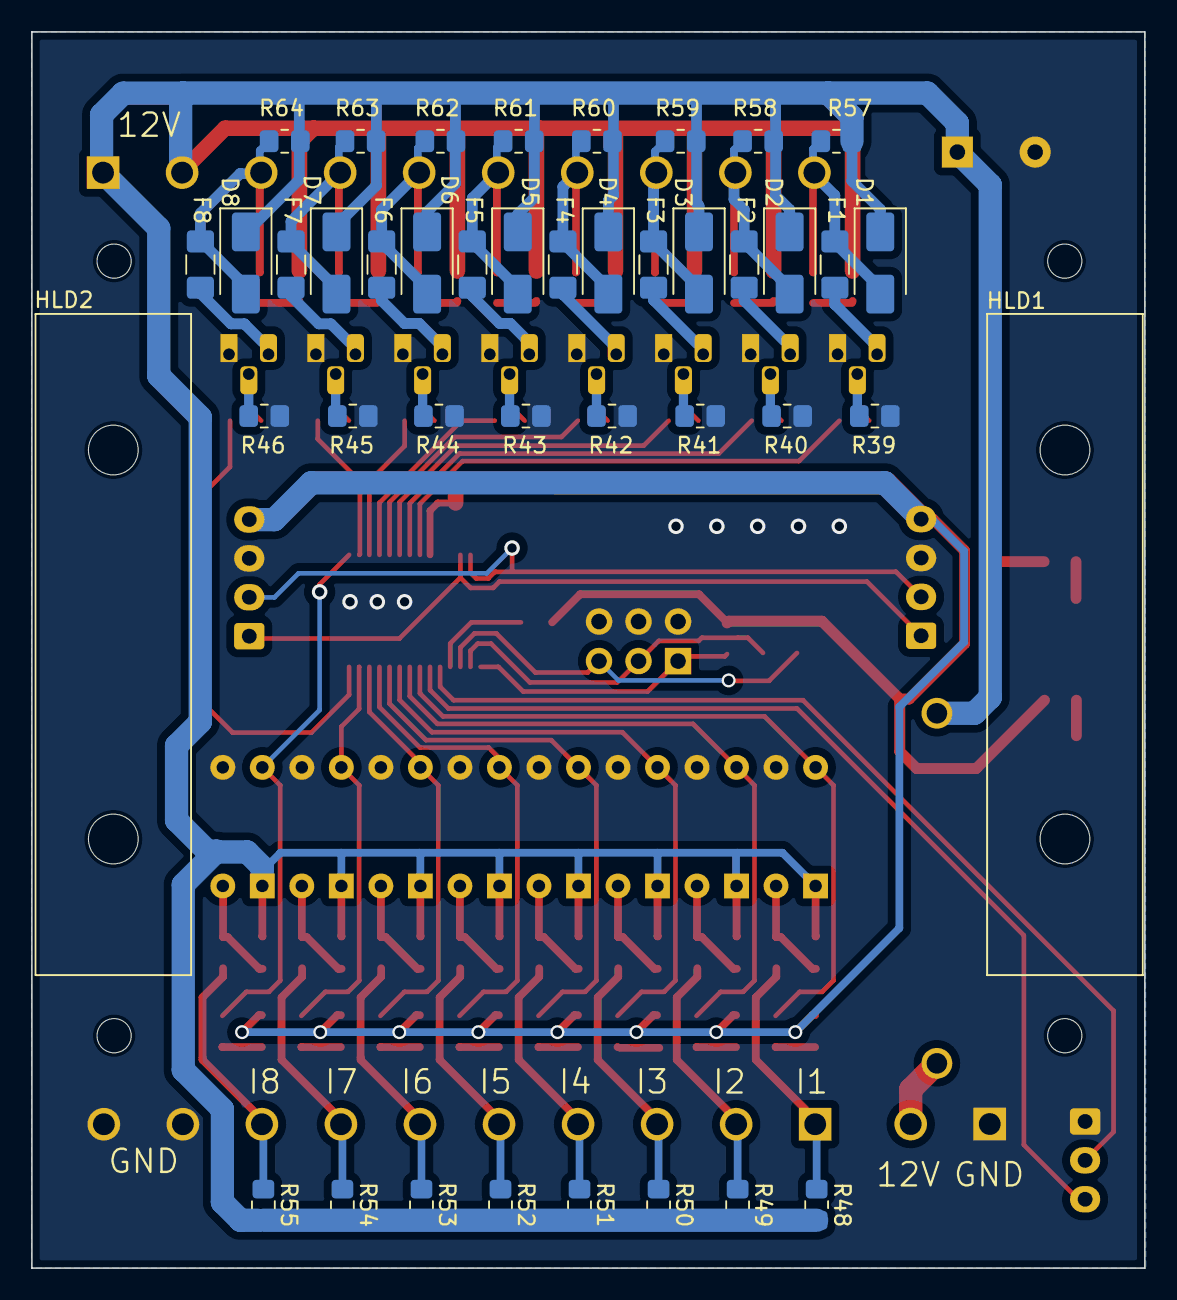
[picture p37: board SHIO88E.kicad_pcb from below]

Board: 2 copper layers, 71.5 x 79.5 mm, 136 parts (40 on the bottom side), 86 nets.

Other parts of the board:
HLD1, HLD2: DINRailAdapter_3xM3_PhoenixContact_1201578

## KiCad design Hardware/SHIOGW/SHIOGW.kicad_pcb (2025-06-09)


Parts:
C1: C_Polarized_Small; CP_Radial_D10.0mm_P5.00mm
C2, C3, C10: C_Small; C_1206_3216Metric_Pad1.33x1.80mm_HandSolder; LCSC C13585
C4: C_Small; C_1206_3216Metric_Pad1.33x1.80mm_HandSolder; LCSC C50254
C5, C8, C9: C_Small; C_0805_2012Metric_Pad1.18x1.45mm_HandSolder; LCSC C49678
C6, C7: C_Small; C_1206_3216Metric_Pad1.33x1.80mm_HandSolder; LCSC C12891
C11, C12: C_Small; C_0805_2012Metric_Pad1.18x1.45mm_HandSolder; LCSC C1710
D1, D5, D6: S1M; D_SMA; LCSC C412437
D2, D3: SMBJ12CA; D_SMB; LCSC C353397
D4: SMBJ28CA; D_SMB; LCSC C353369
D7, D8: D_Zener_Small; Nexperia_CFP3_SOD-123W; LCSC C2903912
F1, F2, F4, F5: Polyfuse; Fuse_1206_3216Metric_Pad1.42x1.75mm_HandSolder; LCSC C2830235
F3: Fuse_Small; FUSE_holder
H1: Conn_01x20; PinSocket_1x20_P2.54mm_Vertical
H2: Conn_02x07_Odd_Even; IDC-Header_2x07_P2.54mm_Vertical
H3, H11: Conn_01x04; JST_XH_B4B-XH-A_1x04_P2.50mm_Vertical
H4: Screw_Terminal_01x02; MSTB 2,5-2-G-5,08
H5, H6, H7, H8, H9: Screw_Terminal_01x03; TerminalBlock_MSTB 2,5 3-G-5,08_v3
H10: Conn_01x02; JST_XH_S2B-XH-A-1_1x02_P2.50mm_Horizontal
H12: Conn_01x05; PinHeader_1x05_P2.54mm_Vertical
IC1: LMR51420XDDCR; LMR51420; Mouser Part Number 595-LMR51420XDDCR
IC2: SN75176; DIP-8_W7.62mm
J1: Conn_01x02; PinHeader_1x02_P2.54mm_Vertical
L1: L_Small; L_Chilisin_BMRx00060630; LCSC C497872
LED1, LED2, LED7: LED_Small; LED_0805_2012Metric_Pad1.15x1.40mm_HandSolder; LCSC C2296
LED3, LED4, LED5, LED6: LED_Small; LED_0805_2012Metric_Pad1.15x1.40mm_HandSolder; LCSC C84256
MH1: MountingHole_Pad; MountingHole_3.2mm_M3_Pad_Via
OP1, OP2: PC817; PC817_custom
Q1, Q2: 2N3904; TO-92_HandSolder
R1: R_Small; R_0805_2012Metric_Pad1.20x1.40mm_HandSolder; LCSC C149504
R2: R_Small; R_0805_2012Metric_Pad1.20x1.40mm_HandSolder; LCSC C17448
R3: R_Small; R_0805_2012Metric_Pad1.20x1.40mm_HandSolder; LCSC C17661
R4: R_Small; R_0805_2012Metric_Pad1.20x1.40mm_HandSolder; LCSC C17408
R5, R6, R20, R21, R22, R23, R29: R_Small; R_0805_2012Metric_Pad1.20x1.40mm_HandSolder; LCSC C17520
R7, R9, R10: R_Small; R_0805_2012Metric_Pad1.20x1.40mm_HandSolder; LCSC C17673
R8: R_Small; R_0805_2012Metric_Pad1.20x1.40mm_HandSolder; LCSC C17437
R11, R14, R15, R16, R17, R27, R28, R32, R33, R34, R35: R_Small; R_0805_2012Metric_Pad1.20x1.40mm_HandSolder; LCSC C17414
R12, R13, R24, R25, R30, R31: R_Small; R_0805_2012Metric_Pad1.20x1.40mm_HandSolder
R18, R19, R26: R_Small; R_0805_2012Metric_Pad1.20x1.40mm_HandSolder; LCSC C17513
TP1, TP2, TP3: TestPoint; TestPoint_Pad_1.0x1.0mm_custom

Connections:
+3.3V: H1.1, H2.3, H3.4, H6.2, H7.2, LED5.2 (A), LED6.2 (A), LED7.2 (A), R9.2, R10.2, R26.1, R27.1, R28.1, R30.2, R31.2, TP1.1
+5V: C6.1, C7.1, C8.2, C9.2, C10.2, H1.20, H2.1, IC2.8 (VCC), L1.2, LED1.2 (A), R1.1, R5.2, R33.2, R34.2, R35.2, TP2.1, TP3.1
+12V: C11.1, C12.1, D1.2 (A), D4.1 (A1), D5.1 (K), D6.1 (K), F3.2, H8.3, H10.2, LED2.2 (A), OP1.1, OP2.1, R12.2, R13.2, R14.2, R15.2, R24.2, R25.1
DIR: H1.5, H2.14, IC2.2 (~RE), IC2.3 (DE), R35.1
GND: C1.2, C2.2, C3.2, C4.2, C6.2, C7.2, C8.1, C9.1, C10.1, D2.2 (A2), D3.2 (A2), D4.2 (A2), D7.2 (A), D8.2 (A), H1.2, H1.19, H2.2, H3.3, H4.2, H5.1, H6.1, H7.1, H9.3, H10.1, H12.5, IC1.1 (GND), IC2.5 (GND), MH1.1, OP1.3, OP2.3, Q1.1 (E), Q2.1 (E), R2.2, R3.2, R6.2, R11.2, R16.2, R17.2, R29.2, R32.2
I1: H1.16, H2.10, H12.2, OP1.4, R20.2, R27.2
I2: H1.18, H2.8, H12.1, OP2.4, R22.2, R28.2
I3: H1.15, H2.12
unnamed: C11.2, OP1.2, R21.1
unnamed: C12.2, OP2.2, R23.1
unnamed: C1.1, C2.1, C3.1, C4.1, D1.1 (K), IC1.3 (VIN), IC1.5 (EN)
unnamed: D2.1 (A1), F2.2, IC2.6 (A), R5.1
unnamed: D3.1 (A1), F1.2, IC2.7 (B), R6.1
unnamed: D5.2 (A), F4.1, H8.2, H11.1, LED3.1 (K), R12.1
unnamed: D6.2 (A), F5.1, H8.1, H11.2, LED4.1 (K), R13.1
unnamed: F3.1, H4.1
unnamed: F2.1, H5.2, J1.2
unnamed: F1.1, H5.3, R8.1
unnamed: H9.2, H11.3, R21.2, R25.2
unnamed: H9.1, H11.4, R23.2, R24.1
unnamed: C5.1, IC1.6 (CB)
unnamed: IC1.4 (FB), R1.2, R2.1
unnamed: C5.2, IC1.2 (SW), L1.1
unnamed: IC2.4 (DI), R4.2, R34.1
unnamed: IC2.1 (RO), R7.1, R33.1
unnamed: J1.1, R8.2
unnamed: LED1.1 (K), R3.1
unnamed: LED2.1 (K), R11.1
unnamed: LED3.2 (A), R14.1
unnamed: LED4.2 (A), R15.1
unnamed: LED5.1 (K), R20.1
unnamed: LED6.1 (K), R22.1
unnamed: LED7.1 (K), R29.1
unnamed: Q1.2 (B), R16.1, R18.2
unnamed: F4.2, Q1.3 (C)
unnamed: Q2.2 (B), R17.1, R19.2
unnamed: F5.2, Q2.3 (C)
O1: H1.7, H12.4, R18.1
O2: H1.14, H12.3, R19.1
RST: H1.3, H2.13
RX: H1.17, H2.7, R7.2, R26.2, R32.1
SCL: H1.13, H2.6, H3.1, R30.1
SDA: H1.8, H2.4, H3.2, R31.1
SEN1: D7.1 (K), H1.9, H2.9, H6.3, R9.1
SEN2: D8.1 (K), H1.10, H2.11, H7.3, R10.1
TX: H1.6, H2.5, R4.1

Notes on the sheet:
GPIO39
GPIO33
GPIO14
GPIO35
GPIO32
GPIO2
GPIO15
GPIO34
GPIO36
GPIO4
GPIO12
GPIO17
GPIO5
GPIO16
GPIO13



Board: 2 copper layers, 75.6 x 79.5 mm, 93 parts (12 on the bottom side), 46 nets.

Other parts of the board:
HLD1, HLD2: DINRailAdapter_3xM3_PhoenixContact_1201578

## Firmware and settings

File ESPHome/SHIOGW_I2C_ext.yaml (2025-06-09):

# SHIOGW with GWHMI and SHIO88E extension modules

esphome:
  name: shiogw-i2c
  name_add_mac_suffix: false
  on_boot:
    - priority: 600
      then:
        - display.page.show: info

esp32:
  board: esp32dev
  framework:
    type: arduino

# Enable logging
logger:

# Enable Home Assistant API
api:
  password: ""
  reboot_timeout: 0s

ota:
  platform: esphome
  password: ""

ethernet:
  id: eth
  type: LAN8720
  mdc_pin: GPIO23
  mdio_pin: GPIO18
  clk_mode: GPIO17_OUT
  phy_addr: 0

globals:
   - id: last_press
     type: 'unsigned long'
     restore_value: no
     initial_value: '0'
   - id: menu_hide_delay
     type: 'int'
     restore_value: no
     initial_value: '30'

time:
  - platform: sntp
    on_time:
      # Every minutes
      - seconds: 0
        minutes: /1
        then:
          - lambda: |-
              int elapsed = (millis() - id(last_press)) / 1000;
              if(elapsed > id(menu_hide_delay)){
                id(my_menu).hide();
                id(clear).show();
              }

web_server:
  version: 3

prometheus:

i2c:
  sda: 13
  scl: 32
  scan: true
  frequency: 400kHz
  id: i2c_bus

mcp23017:
  - id: 'mcp23017_hub'
    address: 0x20

switch:
  - platform: gpio
    name: "O1"
    id: o1
    pin: 12
  - platform: gpio
    name: "O2"
    id: o2
    pin: 33
  - platform: gpio
    id: ioext1_o1
    name: "IOEXT1 O1"
    pin:
      mcp23xxx: mcp23017_hub
      number: 15
      mode:
        output: true
      inverted: false
  - platform: gpio
    id: ioext1_o2
    name: "IOEXT1 O2"
    pin:
      mcp23xxx: mcp23017_hub
      number: 14
      mode:
        output: true
      inverted: false
  - platform: gpio
    id: ioext1_o3
    name: "IOEXT1 O3"
    pin:
      mcp23xxx: mcp23017_hub
      number: 13
      mode:
        output: true
      inverted: false
  - platform: gpio
    id: ioext1_o4
    name: "IOEXT1 O4"
    pin:
      mcp23xxx: mcp23017_hub
      number: 12
      mode:
        output: true
      inverted: false
  - platform: gpio
    id: ioext1_o5
    name: "IOEXT1 O5"
    pin:
      mcp23xxx: mcp23017_hub
      number: 11
      mode:
        output: true
      inverted: false
  - platform: gpio
    id: ioext1_o6
    name: "IOEXT1 O6"
    pin:
      mcp23xxx: mcp23017_hub
      number: 10
      mode:
        output: true
      inverted: false
  - platform: gpio
    id: ioext1_o7
    name: "IOEXT1 O7"
    pin:
      mcp23xxx: mcp23017_hub
      number: 9
      mode:
        output: true
      inverted: false
  - platform: gpio
    id: ioext1_o8
    name: "IOEXT1 O8"
    pin:
      mcp23xxx: mcp23017_hub
      number: 7
      mode:
        output: true
      inverted: false
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

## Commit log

2025-12-10 GWHMI: updated symbol fields SHIO88E: fixed silkscreen texts
    [GWHMI.kicad_pcb, GWHMI.kicad_sch, SHIO88E.kicad_pcb]
2026-01-28 Added LRMNT and SHIOADS boards
    [1759020.step, LRMNT.kicad_pcb, LRMNT.kicad_sch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]
